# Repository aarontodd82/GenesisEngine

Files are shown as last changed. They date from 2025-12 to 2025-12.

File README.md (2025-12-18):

# Genesis Engine

**Authentic Sega Genesis / Mega Drive sound on real hardware.**

The Genesis Engine is a sound board and library that brings the iconic sound of the Sega Genesis to your projects. Featuring the **YM2612 FM synthesizer** and **SN76489 PSG** chips on a board easily controlled by Teensy/Arduino/ESP32

Play VGM music files, stream audio directly from an emulator, or use it as a standalone synthesizer. 

## The Board

Schematics, KiCad, & Gerbers are in the hardware folder, but if you just want to grab one:
[https://www.tindie.com/products/40905/](https://www.tindie.com/products/40905/)

- **Stereo output** — Full left/right channel separation
- **Accurate clocks** — Crystal oscillators tuned for correct pitch
- **FM and PSG in tune** — Both chips share a proper clock relationship
- **Upgraded Op-amp** — Designed for low noise

## Features

- **Real Chips** — YM2612 FM synthesis and SN76489 PSG, not emulation
- **VGM Playback** — Play music from Genesis, Mega Drive, Game Gear, and Master System
- **Multiple Playback Modes**
  - Flash memory (PROGMEM) for standalone operation
  - SD card for large music libraries
  - Serial streaming from PC
  - Real-time streaming from emulators (BlastEm)
- **Synthesis Utilities** — Direct chip control for custom sounds, MIDI synths, and sound effects
- **Cross-Platform** — Teensy 4.x, ESP32, Arduino Mega/Uno, and more
- **VGZ Support** — Native decompression on Teensy/ESP32
- **PCM/DAC Support** — Sampled drums and vocals on YM2612 channel 6
- **Smart Memory Management** — Automatically adapts to your board's capabilities

## Supported Systems for VGM

| System | FM Chip | PSG Chip | Support |
|---|---|---|---|
| Sega Genesis / Mega Drive | YM2612 | SN76489 | Full |
| Sega Master System | — | SN76489 | PSG only |
| Sega Game Gear | — | SN76489 | PSG only |
| ColecoVision | — | SN76489 | PSG only |
| IBM PCjr | — | SN76489 | PSG only |
| Tandy 1000 PCs | — | SN76489 | PSG only |

## Quick Start

### Wiring

Connect the Genesis Engine board to your microcontroller.

| Board Pin | Function | Arduino/Teensy | ESP32 | Configurable? |
|---|---|---|---|---|
| WR_P | PSG write strobe (active low) | 2 | 16 | Yes |
| WR_Y | YM2612 write strobe (active low) | 3 | 17 | Yes |
| IC_Y | YM2612 reset (active low) | 4 | 25 | Yes |
| A0_Y | YM2612 address/data select | 5 | 26 | Yes |
| A1_Y | YM2612 port select | 6 | 27 | Yes |
| SCK | Shift register clock | SPI | SPI | See below |
| SDI | Shift register data (MOSI) | SPI | SPI | See below |
| VCC | 5V power | — | — | — |
| GND | Ground | — | — | — |

**ESP32 Note:** GPIO 0-3 (boot/serial), 6-11 (flash), and 12/15 (boot strapping) must be avoided. The defaults above are safe for ESP32-WROOM-32 dev boards.

**SPI Pins** — By default, the library uses hardware SPI for fast data transfer. These pins are fixed per board:

| Board | SCK | SDI (MOSI) |
|---|-----|---|
| Teensy 4.x | 13 | 11 |
| ESP32 | 18 | 23 |
| Uno | 13 | 11 |
| Mega | 52 | 51 |

If you need different pins for SCK/SDI, set `USE_HARDWARE_SPI` to 0 in `GenesisBoard.cpp` to enable software SPI on any GPIO.

### Basic Usage

```cpp
#include <GenesisEngine.h>
#include "music.h"  // Your VGM converted to a header file

// Pin connections (directly configurable)
const uint8_t WR_P = 2, WR_Y = 3, IC_Y = 4, A0_Y = 5, A1_Y = 6;

// SCK/SDI ignored when using hardware SPI (default)
GenesisBoard board(WR_P, WR_Y, IC_Y, A0_Y, A1_Y, 0, 0);
GenesisEngine player(board);

void setup() {
    board.begin();
    player.play(music_data, music_length);
    player.setLooping(true);
}

void loop() {
    player.update();  // Call frequently for proper timing
}
```

### SD Card Playback

```cpp
#include <GenesisEngine.h>
#include <SD.h>

const uint8_t WR_P = 2, WR_Y = 3, IC_Y = 4, A0_Y = 5, A1_Y = 6;
GenesisBoard board(WR_P, WR_Y, IC_Y, A0_Y, A1_Y, 0, 0);
GenesisEngine player(board);

void setup() {
    SD.begin(BUILTIN_SDCARD);  // Teensy 4.1 built-in SD
    board.begin();
    player.playFile("/music/greenhill.vgm");
}

void loop() {
    player.update();
}
```

## Playback Modes

### Flash Memory (PROGMEM)
Store music directly in your microcontroller's flash. Convert VGM files with the included tool:

```bash
python examples/BasicPlayback/vgm2header.py song.vgm
```

### SD Card
Play VGM and VGZ files directly from SD. The SDCardPlayer example includes an interactive serial menu for browsing and playback control. Works best on Teensy or ESP32. Mega has limited support (see Platform Notes). Not supported on Arduino Uno due to RAM limits.

### Serial Streaming
Stream VGM files from your PC in real-time:

```bash
python examples/SerialStreaming/stream_vgm.py song.vgm
```

### Emulator Bridge
Stream audio directly from BlastEm or other Genesis emulators to hear games on real hardware as you play.

## Platform Notes

| Feature | Teensy 4.x | ESP32 | Mega | Uno |
|---|---|---|---|-----|
| PROGMEM playback | Yes | Yes | Yes | Yes |
| Serial streaming | Yes | Yes | Yes | Yes |
| SD card | Built-in | Yes | Limited* | No |
| VGZ decompression | Native | Native | Via tools | Via tools |
| PCM buffer size | 8KB+ | 4KB | 512 bytes | 256 bytes |

**Teensy 4.x is recommended**, especially for SD card playback. It offers fast GPIO, large memory, and built-in SD on the 4.1.

**Arduino Uno/Mega Limitation:** Due to AVR's 16-bit PROGMEM addressing, flash playback is limited to ~16KB (Uno) or ~60KB (Mega). Use `--strip-dac` when converting to fit more music. Uno does not support SD card (insufficient RAM). See the BasicPlayback example README for details.

*Mega SD support requires software SPI for the shift register due to pin conflicts. Results may vary—some VGM files with heavy DAC usage may have timing issues.

**ESP32 SD Note:** When using SD cards on ESP32, the shift register must use different pins (GPIO 4/13) than other examples (GPIO 18/23) because the SD card needs the hardware SPI bus. See the SDCardPlayer README for full wiring details.

## Examples

- **BasicPlayback** — VGM playback from flash memory
- **SDCardPlayer** — SD card player with serial menu
- **SerialStreaming** — Stream music from PC over USB
- **EmulatorBridge** — Real-time audio from Genesis emulators
- **SimpleSynth** — Direct chip control demo using synthesis utilities
- **MIDISynth** — Full MIDI synthesizer with voice allocation and patch management

## Tools

Each example includes relevant Python tools:

| Tool | Location | Description |
|---|---|---|
| `vgm2header.py` | examples/BasicPlayback/ | Convert VGM/VGZ to C header files |
| `vgm_prep.py` | examples/SDCardPlayer/ | Prepare VGM for SD (decompress, strip DAC) |
| `stream_vgm.py` | examples/SerialStreaming/ | Stream VGM from PC to board |

## Synthesis Utilities

For direct chip control without VGM playback, the library includes synthesis utilities in `synth/`:

```cpp
#include <GenesisBoard.h>
#include <synth/FMPatch.h>
#include <synth/FMFrequency.h>
#include <synth/PSGFrequency.h>
#include <synth/DefaultPatches.h>

GenesisBoard board(2, 3, 4, 5, 6, 13, 11);
FMPatch patch;

void setup() {
    board.begin();

    // Load a built-in FM patch
    memcpy_P(&patch, &defaultFMPatches[0], sizeof(FMPatch));
    FMPatchUtils::loadToChannel(board, 0, patch);
}

void playNote(uint8_t note) {
    FMFrequency::writeToChannel(board, 0, note);
    FMFrequency::keyOn(board, 0);
}

void stopNote() {
    FMFrequency::keyOff(board, 0);
}
```

### Available Modules

| Header | Description |
|---|---|
| `synth/FMFrequency.h` | MIDI note to YM2612 frequency conversion, key on/off |
| `synth/PSGFrequency.h` | MIDI note to PSG tone values, volume control |
| `synth/FMPatch.h` | FM patch structure and loading utilities |
| `synth/PSGEnvelope.h` | Software envelope generator for PSG |
| `synth/DefaultPatches.h` | 8 built-in FM patches and 4 PSG envelopes |

See the **SimpleSynth** example for a complete demo, or **MIDISynth** for a full synthesizer implementation.

## License

LGPL-2.1 — See [LICENSE](LICENSE) for details.

## Links

- [GitHub Repository](https://github.com/fm-90s/GenesisEngine)
- [FM-90s](https://fm-90s.com)

---

*Genesis Engine is not affiliated with or endorsed by Sega. Sega Genesis and Mega Drive are trademarks of Sega Corporation.*

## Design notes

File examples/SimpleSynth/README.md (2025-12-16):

# SimpleSynth

Direct chip control demo for the GenesisEngine board. Play notes on the YM2612 FM chip and SN76489 PSG using simple serial commands.

This example demonstrates the **synthesis utilities** in the GenesisEngine library, showing how to control the chips without VGM playback.

## Features

- Load FM patches from the built-in library
- Play notes by MIDI number
- PSG tone generation
- Simple serial command interface

## Quick Start

1. Upload the sketch to your board
2. Open Serial Monitor at 115200 baud
3. Try these commands:
   - `n60` — Play middle C on FM
   - `p3` — Switch to Lead Synth patch
   - `n72` — Play note 72 (C5)
   - `s` — Stop note
   - `t60` — Play middle C on PSG
   - `q` — Silence all
   - `?` — Show help

## Serial Commands

| Command | Description |
|---|---|
| `n<note>` | Play FM note (0-127, 60 = middle C) |
| `s` | Stop FM note |
| `p<num>` | Change FM patch (0-7) |
| `t<note>` | Play PSG tone on channel 0 |
| `q` | Silence all |
| `?` | Show help |

## Built-in Patches

| Slot | Sound |
|---|---|
| 0 | Bright EP (Electric Piano) |
| 1 | Synth Bass |
| 2 | Brass |
| 3 | Lead Synth |
| 4 | Organ |
| 5 | Strings |
| 6 | Pluck/Guitar |
| 7 | Bell/Chime |

## Using the Synthesis Utilities

This example shows the basics of direct chip control:

```cpp
#include <GenesisBoard.h>
#include <synth/FMPatch.h>
#include <synth/FMFrequency.h>
#include <synth/PSGFrequency.h>
#include <synth/DefaultPatches.h>

// Load a patch
FMPatch patch;
memcpy_P(&patch, &defaultFMPatches[0], sizeof(FMPatch));
FMPatchUtils::loadToChannel(board, 0, patch);

// Play a note
FMFrequency::writeToChannel(board, 0, 60);  // Set frequency
FMFrequency::keyOn(board, 0);               // Start note

// Stop the note
FMFrequency::keyOff(board, 0);

// PSG tone
PSGFrequency::playNote(board, 0, 60, 2);    // Channel 0, note 60, volume 2
```

## Building On This

For a full synthesizer with MIDI support, see the **MIDISynth** example.

## Pin Configuration

Adjust the pin definitions in the sketch to match your wiring to the Genesis Engine board.

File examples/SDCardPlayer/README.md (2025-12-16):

# SDCardPlayer

Play VGM files from an SD card with an interactive serial menu. This example turns the Genesis Engine into a standalone music player for Sega Genesis/Mega Drive soundtracks.

## Wiring

### Recommended: Teensy 4.1

Teensy 4.1 provides the best experience with built-in SD card slot, plenty of RAM, and full VGZ support.

### Arduino Uno - NOT SUPPORTED

Only 2KB RAM - not enough for SD library.

### Arduino Mega - Limited Support

Works but results may vary. Software SPI for the shift register is slower than Teensy's hardware SPI, which may affect timing on some VGM files. Use `vgm_prep.py` to prepare files.

The SD card and shift register both use SPI, but the CD74HCT164E shift register has no chip select pin. To avoid conflicts, **the shift register MUST use different pins** than the SD card.

| Genesis Engine Board | Arduino Pin |
|---|---|
| WR_P (PSG write) | 2 |
| WR_Y (YM2612 write) | 3 |
| IC_Y (YM2612 reset) | 4 |
| A0_Y (YM2612 addr)  | 5 |
| A1_Y (YM2612 port)  | 6 |
| **Shift CLK** | **7** ⚠️ |
| **Shift DATA** | **8** ⚠️ |

⚠️ **Do NOT connect shift register to pins 51/52!** Those are used by the SD card.

SD card uses Mega's hardware SPI:

| SD Card Module | Arduino Pin |
|---|---|
| CS | 53 |
| MOSI | 51 |
| MISO | 50 |
| SCK | 52 |
| VCC | 5V |
| GND | GND |

**Teensy 4.1:**

Uses the built-in SD card slot - no SD wiring needed. Genesis board can use the default hardware SPI pins since there's no conflict.

### ESP32 - Full Support

ESP32 works great with SD cards, but requires **different shift register pins** than other examples. The SD card needs the hardware SPI bus, and since the shift register has no chip select, they cannot share pins.

⚠️ **IMPORTANT:** The shift register pins are DIFFERENT from SerialStreaming and other examples!

| Genesis Engine Board | ESP32 GPIO |
|---|---|
| WR_P (PSG write) | 16 |
| WR_Y (YM2612 write) | 17 |
| IC_Y (YM2612 reset) | 25 |
| A0_Y (YM2612 addr)  | 26 |
| A1_Y (YM2612 port)  | 27 |
| **Shift CLK** | **4** ⚠️ |
| **Shift DATA** | **13** ⚠️  |

⚠️ **Do NOT use GPIO 18/23 for shift register!** Those are used by the SD card.

SD card uses ESP32's hardware SPI (VSPI):

| SD Card Module | ESP32 GPIO |
|---|---|
| CS | 5 |
| MOSI | 23 |
| MISO | 19 |
| SCK | 18 |
| VCC | 3.3V or 5V (check your module) |
| GND | GND |

**PlatformIO users:** Use the `esp32_sd` environment, not `esp32`.

---

## How to Use

1. **Prepare your files**: Place `.vgm` files in the root of a FAT32-formatted SD card. On Arduino Mega, use `vgm_prep.py` to convert `.vgz` files first:
   ```
   python vgm_prep.py song.vgz -o song.vgm
   ```

2. **Upload the sketch**: Open `SDCardPlayer.ino` in the Arduino IDE and upload it to your board.

3. **Open the Serial Monitor**: Go to **Tools > Serial Monitor** (or press `Ctrl+Shift+M`). Set the baud rate to **115200** using the dropdown in the bottom-right corner. You should see a welcome message and a `>` prompt.

4. **Control playback**: Type commands in the input field at the top and press Enter:
   | Command | Action |
   |---------|--------|
   | `list` | Show available VGM files |
   | `play 1` | Play file #1 (or use filename) |
   | `playlist name` | Play a playlist (name.txt) |
   | `stop` | Stop playback |
   | `pause` | Pause/resume |
   | `next` / `prev` | Skip tracks |
   | `loop` | Toggle looping |
   | `info` | Show current track status |
   | `help` | Full command list |

   Tip: You can also just type a number (e.g. `3`) to quickly play that file.

## Playlists

Create a `.txt` file on your SD card starting with `#PLAYLIST`:

```
#PLAYLIST
# My playlist - lines starting with # are comments
#
# Optional settings:
#   :shuffle  - randomize song order
#   :loop     - restart playlist when finished
#
# Songs: one per line, optionally with play count
#   song.vgm      - plays once
#   song.vgm,3    - plays 3 times (loops twice)
#
:shuffle
:loop

greenhill.vgm,2
starlight.vgm
boss.vgm,3
```

**Commands:**
- `playlist mylist` - loads and plays `mylist.txt`

**Auto-start:** Name your playlist `auto.txt` and it will play automatically when the board powers on - no serial connection needed.

## Tech Primer

The sketch creates a `GenesisBoard` (hardware driver) and `GenesisEngine` (player) instance. On startup, it initializes the SD card and scans the root directory for `.vgm`/`.vgz` files, storing up to 50 filenames (20 on AVR).

The main loop does two things: calls `player.update()` to process VGM commands in real-time, and polls the serial port for user input. Commands are parsed in `processCommand()` which maps text input to player API calls like `playFile()`, `pause()`, and `stop()`.

When you play a file, `GenesisEngine` opens it via `SDSource`, parses the VGM header for metadata (duration, loop points, chips used), then streams commands to the hardware. The player uses `micros()` to track elapsed time and processes chip writes at the correct 44100 Hz sample rate.

**Platform differences**: Teensy and ESP32 have enough RAM to decompress VGZ files on-the-fly and buffer PCM samples. AVR boards (Uno/Mega) lack this, so you must pre-process files with `vgm_prep.py`, which decompresses VGZ and inlines DAC samples directly into the command stream at a reduced sample rate.

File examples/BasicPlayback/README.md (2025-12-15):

# BasicPlayback Example

Play VGM/VGZ files from flash memory using the Genesis Engine library.

## Quick Start

A sample file `greenhill.vgz` is included. Convert it first:

1. **Convert your VGM file:**
   ```
   python vgm2header.py your_song.vgz
   ```
   The wizard will ask which platform you're using and handle the rest.

2. **Update the sketch:**
   ```cpp
   #include "your_song.h"
   ```
   And update the playChunked() calls:
   ```cpp
   player.playChunked(your_song_chunks, your_song_chunk_sizes,
                      YOUR_SONG_NUM_CHUNKS, YOUR_SONG_TOTAL_LEN);
   ```

3. **Upload and enjoy!**

## Batch Conversion

Skip the wizard with `-p` to specify platform directly:
```
python vgm2header.py *.vgz -p teensy41
```

## Platform Limits

Flash memory limits for VGM data vary by platform:

| Platform | Max VGM Size | Notes |
|---|---|---|
| **Teensy 4.1** | ~7 MB | Recommended for large files |
| **Teensy 4.0** | ~1.5 MB | |
| **ESP32** | ~2 MB | |
| **RP2040** | ~1.5 MB | |
| **Arduino Mega** | **60 KB** | 16-bit PROGMEM pointer limit |
| **Arduino Uno** | **16 KB** | Very limited flash |

### Arduino Limitations

**Arduino Uno and Mega have severe flash limitations** due to AVR's 16-bit PROGMEM addressing. The converter will automatically truncate files to fit.

For Arduino, use `--strip-dac` to remove PCM samples (drums):
```
python vgm2header.py song.vgz -p mega --strip-dac
```

This often reduces file size by 90%+ while keeping all FM and PSG music. A 500KB VGM typically becomes 30-50KB without DAC.

**For larger music libraries on Arduino, use the SDCardPlayer example instead.**

## Pin Configuration

Adjust the pin definitions in the sketch to match your wiring to the Genesis Engine board.

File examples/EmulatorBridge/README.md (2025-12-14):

# EmulatorBridge

This example turns your Genesis Engine board into a real-time audio output device for the BlastEm emulator. Play any Genesis/Mega Drive game and hear authentic sound through real YM2612 and SN76489 chips.

## Quick Start

1. **Upload the sketch** to your Genesis Engine board using the Arduino IDE or PlatformIO
2. **Download BlastEm** from [https://github.com/aarontodd82/blastem-genesis-engine/releases](https://github.com/aarontodd82/blastem-genesis-engine/releases) (Windows, macOS, and Linux binaries available)
3. **Connect the board** via USB
4. **Run BlastEm** with any ROM: `./blastem game.bin`

If the board is detected, you'll see: "Genesis Engine audio board found, using hardware audio"

That's it - all game audio now plays through the real chips.

## How It Works

When you play a game in BlastEm, the emulator intercepts every write to the YM2612 (FM synth) and SN76489 (PSG) registers. Instead of just emulating the sound, it streams those writes over USB serial to your Genesis Engine board at 1 Mbaud.

The board receives these commands in real-time and writes them to the actual chips. Audio stays in sync with the game since timing comes directly from the emulator.

### Board Compatibility

| Board | Buffer | FM + PSG | DAC/PCM |
|---|---|---|---|
| Arduino Uno | 512 bytes | Real hardware | Software (from PC) |
| Arduino Mega | 2 KB | Real hardware | Software (from PC) |
| Teensy 4.x | 32 KB | Real hardware | Real hardware |
| ESP32 | 16 KB | Real hardware | Real hardware |

**Arduino Uno/Mega**: FM synthesis and PSG play through real chips. DAC samples (used for voices, drums, sound effects in some games) play through BlastEm's software emulation on your PC. This hybrid approach works because DAC streaming requires more bandwidth than constrained boards can handle.

**Teensy 4.x/ESP32**: Full hardware audio - FM, PSG, and DAC all play through the real chips. BlastEm mutes its software audio completely.

## Troubleshooting

**No hardware detected**
- Check USB connection
- Verify the sketch is uploaded (LED should be on)
- Linux users: add yourself to the `dialout` group

**Audio glitches**
- Don't use fast-forward or turbo modes
- Avoid USB hubs - connect directly
- Close other programs using serial ports

**Notes hang when pausing**
- This is handled automatically - BlastEm silences the hardware when you pause or open menus

## Technical Details

### Protocol

The bridge uses VGM-style commands for chip writes:

| Command | Bytes | Description |
|---|---|---|
| `0x50 <val>` | 2 | Write to PSG |
| `0x52 <reg> <val>` | 3 | Write to YM2612 Port 0 |
| `0x53 <reg> <val>` | 3 | Write to YM2612 Port 1 |
| `0x61 <lo> <hi>` | 3 | Wait N samples (44.1kHz) |
| `0x62` | 1 | Wait 1/60 sec (NTSC frame) |
| `0x63` | 1 | Wait 1/50 sec (PAL frame) |
| `0x70-0x7F` | 1 | Wait 1-16 samples |
| `0x66` | 1 | End stream / reset |
| `0xAA` | 1 | Ping (connection handshake) |

### Connection Handshake

```
BlastEm                    Board
   |                         |
   |------- 0xAA PING ------>|
   |                         |
   |<-- 0x0F ACK + TYPE -----|
   |<------ 0x06 READY ------|
   |                         |
   |==== streaming begins ===|
```

The board type in the handshake response tells BlastEm which audio mode to use:
- Types 1-2 (Uno/Mega): Hybrid mode - stream FM/PSG to hardware, keep software DAC
- Types 4-5 (Teensy/ESP32): Full hardware mode - stream everything, mute software audio

### Data Flow

```
BlastEm (emulator)              USB Serial (1Mbaud)              Genesis Engine
┌──────────────────┐                                           ┌─────────────────┐
│  68000 CPU write │                                           │                 │
│  to $A04000      │ ──── 0x52 reg val ────────────────────────> Real YM2612    │
│  (YM2612)        │                                           │                 │
│                  │                                           │                 │
│  Z80 write to    │                                           │                 │
│  $7F11 (PSG)     │ ──── 0x50 val ────────────────────────────> Real SN76489   │
└──────────────────┘                                           └─────────────────┘
        │
        └── Wait commands encode timing at 44.1kHz sample resolution
```

### Timing Architecture

BlastEm runs with cycle-accurate emulation and tracks exactly when each register write occurs. It converts these timestamps into VGM-style wait commands:

1. **In BlastEm**: A `serial_bridge.c` module hooks into `ym2612.c` and `psg.c`
2. **Timing accumulation**: Cycles since last write are converted to 44.1kHz samples
3. **Wait encoding**: Uses efficient short waits (`0x70-0x7F`) when possible
4. **On the board**: `micros()` timing ensures writes happen at the correct intervals

The board's ring buffer absorbs USB timing jitter, keeping playback smooth even if USB batches data irregularly.

### Arduino Delay Buffer

On Arduino Uno/Mega, a frame-delay buffer (~67ms) synchronizes hardware FM/PSG with software DAC audio from BlastEm. This ensures both audio sources stay in sync despite different playback latencies.

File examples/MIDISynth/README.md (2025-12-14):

# MIDISynth

A MIDI synthesizer for the GenesisEngine board. Play the YM2612 FM chip and SN76489 PSG from any DAW, keyboard, or sequencer using real Sega Genesis hardware.

## Platform Requirements

**Teensy 4.x** works as a standalone USB MIDI instrument. Connect it to your computer and it appears as "Genesis Engine" in your MIDI device list. You can load custom patches using the included `genesis_patch.py` script, though the companion app below offers more features.

**Arduino Uno/Mega** requires the [GenesisEngineSynthApp](https://github.com/aarontodd82/GenesisEngineSynthApp) companion application. The app bridges your computer's MIDI to the Arduino over serial. Download releases for Windows, Mac, and Linux from the GitHub page. On Windows, you'll also need [LoopMIDI](https://www.tobias-erichsen.de/software/loopmidi.html) to create a virtual MIDI port for your DAW.

## Setup

### Teensy

1. In Arduino IDE: **Tools → USB Type → Serial + MIDI**
2. Upload the sketch
3. Connect via USB - your computer sees "Genesis Engine"

### Arduino

1. Upload the sketch
2. Run GenesisEngineSynthApp
3. Select your Arduino's COM port and connect
4. On Windows: Create a LoopMIDI port, select it in the app, then route your DAW to that port

## Loading Patches

The synth starts with 8 built-in FM patches. To load custom patches:

**Using GenesisEngineSynthApp** (recommended): The app provides a patch browser, bank management, and real-time parameter editing.

**Using genesis_patch.py** (Teensy only):
```bash
pip install python-rtmidi
python genesis_patch.py load piano.tfi 1      # Load to channel 1
python genesis_patch.py bank sonic2.gyb       # Load a GYB bank
```

Supported formats: TFI, DMP, GYB. Find patches at [VGMRips](https://vgmrips.net) or create your own with [Furnace Tracker](https://github.com/tildearrow/furnace).

## Quick Reference

### MIDI Channels

| Channel | Hardware |
|---|---|
| 1-6 | YM2612 FM |
| 7-9 | SN76489 Tone |
| 10 | SN76489 Noise |

### Synth Modes

- **Multi-timbral** (default): Each FM channel plays independently
- **Poly**: Channel 1 controls all 6 FM voices polyphonically

Switch with CC 126 (multi) or CC 127 (poly).

### Key MIDI Controls

| Message | Effect |
|---|---|
| Program Change | Select patch slot |
| Pitch Bend | ±2 semitones (FM) |
| CC 1 | Vibrato depth (FM) |
| CC 7 | Volume |
| CC 10 | Pan (FM) |
| CC 64 | Sustain pedal (FM) |

### Real-Time Parameter CCs

| CC | Parameter |
|----|---|
| 14 | Algorithm (0-7) |
| 15 | Feedback (0-7) |
| 16-19 | Operator 1-4 Total Level |

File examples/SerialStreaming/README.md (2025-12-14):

# SerialStreaming

Stream VGM files from your PC directly to the Genesis Engine board over USB. No SD card needed - just plug in, run the script, and listen to Sega Genesis music on real hardware.

## Requirements

- Arduino Uno, Mega, Teensy 4.x, or ESP32
- Python 3 with pyserial (`pip install pyserial`)
- USB cable

## Quick Start

1. Upload `SerialStreaming.ino` to your board
2. Run the streamer:

```bash
python stream_vgm.py
```

This launches an interactive wizard that finds VGM files and your board automatically.

## Command Line Usage

```bash
# Basic playback
python stream_vgm.py song.vgm

# Specify port manually
python stream_vgm.py song.vgm --port COM3
python stream_vgm.py song.vgm --port /dev/ttyUSB0

# Loop forever (Ctrl+C to stop)
python stream_vgm.py song.vgm --loop

# Loop 3 times
python stream_vgm.py song.vgm --loop 3

# List available serial ports
python stream_vgm.py --list-ports
```

## DAC/PCM Options

Some VGM files contain sampled audio (drums, voices). These require high throughput and may not play smoothly on slower boards.

```bash
# Reduce DAC sample rate (1=full, 2=half, 4=quarter)
python stream_vgm.py song.vgm --dac-rate 2

# Strip DAC entirely (FM/PSG only, smallest bandwidth)
python stream_vgm.py song.vgm --no-dac
```

By default, Uno/Mega use 1/4 DAC rate automatically. Teensy uses full rate.

## Troubleshooting

**No response from device**
- Make sure the sketch is uploaded
- Check that the baud rate matches (default: 1000000)
- Try unplugging and replugging the USB cable

**Audio glitches or stuttering**
- Try `--dac-rate 2` or `--dac-rate 4`
- Use `--no-dac` for problematic files
- Ensure no other programs are using the serial port

**Wrong port detected**
- Use `--list-ports` to see available ports
- Specify manually with `--port`

---

## How It Works

The system streams VGM commands from your PC to the board in real-time using a custom binary protocol.

### Architecture

```
PC (stream_vgm.py)                    Board (SerialStreaming.ino)
┌──────────────────┐                  ┌──────────────────────────┐
│ Load VGM/VGZ     │                  │                          │
│       ↓          │                  │   Ring Buffer            │
│ Preprocess:      │   1Mbaud USB     │   ┌────────────────┐     │
│ - Inline PCM     │ ═══════════════> │   │ ░░░░░░░▓▓▓▓▓▓ │     │
│ - Optimize waits │   Chunked data   │   └───────┬────────┘     │
│ - Reduce DAC rate│                  │           ↓              │
│       ↓          │                  │   Command Parser         │
│ Chunk + checksum │                  │           ↓              │
│       ↓          │                  │   ┌───────┴───────┐      │
│ Send via serial  │                  │   ↓               ↓      │
└──────────────────┘                  │ YM2612 (FM)   SN76489    │
                                      └──────────────────────────┘
```

### Protocol

Data is sent in checksummed chunks to handle serial errors:

```
[0x01][length][data...][XOR checksum]
```

The board responds with:
- `0x06` (ACK) - chunk received OK, ready for more
- `0x15` (NAK) - bad checksum, please resend

### Timing

VGM files run at 44100 Hz. The board uses `micros()` to schedule commands precisely. Wait commands tell the board how many samples to delay before the next chip write.

### Buffering

The board fills its ring buffer before starting playback:
- Uno: 512 bytes (384 before play)
- Mega: 2KB (1.5KB before play)
- Teensy: 4KB (3KB before play)

This absorbs USB latency jitter and keeps playback smooth.

### DAC Handling

VGM files store PCM samples in a separate data block. The Python script inlines these samples directly into the command stream, so the board doesn't need RAM for sample storage. For slow boards, it skips samples to reduce bandwidth.

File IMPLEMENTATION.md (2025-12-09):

# FM-90s Genesis Engine - Implementation Guide

## Project Overview

**Name:** FM-90s Genesis Engine
**Purpose:** A simple, multi-platform Arduino library for playing VGM files on the FM-90s Genesis Engine sound board (YM2612 FM + SN76489 PSG)
**Target Audience:** Hobbyists and makers who want easy VGM playback with minimal configuration

### Supported Systems (VGM Playback)

| System | FM Chip | PSG Chip | Support Level |
|---|---|---|---|
| Sega Genesis / Mega Drive | YM2612 | SN76489 | Full |
| Sega Game Gear | - | SN76489 | Full (PSG only) |
| Sega Master System | - | SN76489 | Full (PSG only) |

---

## Goals

1. **Maximum Compatibility** - Works on Arduino Uno through Teensy 4.1
2. **Zero Configuration** - Auto-detects platform and enables appropriate features
3. **Simple API** - Users can play music with minimal code
4. **Self-Contained** - Single library include, no complex dependencies
5. **Progressive Features** - Basic features everywhere, advanced features on capable hardware

---

## Platform Support Matrix

| Feature | Arduino AVR | ESP32 | Teensy 4.x |
|---|---|---|---|
| PROGMEM playback | Yes | Yes | Yes |
| Serial streaming | Yes (VGM only) | Yes | Yes |
| SD card playback | With SD module | Yes | Yes (built-in on 4.1) |
| VGZ decompression | No (use tool) | Yes | Yes |
| USB MIDI instrument | No | No | Yes |
| DAC pre-render | No | No | Yes (with Audio Board) |
| Large buffers | No (256B) | Yes (4KB) | Yes (8KB+) |

---

## Architecture Decisions

### Platform Detection
- Automatic via compiler macros (`TEENSYDUINO`, `ARDUINO_ARCH_AVR`, etc.)
- No user configuration required
- Optional override defines if needed

### Pin Configuration
- Runtime configurable via constructor
- User passes their pin numbers, library handles the rest
- No compile-time pin definitions to confuse users

### VGM/VGZ Handling
- **Arduino AVR:** Python tool converts VGZ → VGM → C header (PROGMEM)
- **Arduino AVR Serial:** Requires pre-decompressed VGM files
- **Teensy/ESP32:** Native VGZ decompression using uzlib

### Timing Strategy
- Cooperative `update()` model with `micros()` for basic playback
- Timer interrupts on Teensy for sample-accurate timing
- Smart timing pattern from reference implementation (tracks elapsed time, only waits if needed)

### SD Card
- Conditional compilation - only included if platform supports it
- Uses standard Arduino SD library for compatibility
- Teensy uses `BUILTIN_SDCARD` for 4.1

### Serial Menu
- Optional include (`GenesisEngineMenu.h`)
- Commands: list files, play, stop, pause, next, previous, loop toggle
- Works over any Stream (Serial, Serial1, etc.)

### MIDI Instrument Mode
- Teensy-only (USB MIDI)
- Phase 2 feature
- Maps MIDI notes to YM2612 FM channels
- **Deflemask Patch Support:** Load .dmp (Deflemask Preset) files to use custom FM instruments
  - Deflemask is a popular chiptune tracker that exports YM2612 patches
  - Goal: Load patches from SD card and use them as MIDI instruments
  - Each MIDI channel can have a different Deflemask patch assigned

### DAC Pre-render (Phase 2)
- Teensy with Audio Board only
- Pre-renders PCM to temp file for smooth playback
- Based on reference implementation's proven approach

---

## Formats Supported

### VGM (Video Game Music)
- Standard format, widely available
- Large file sizes, especially with DAC
- Best for Teensy/ESP32 with plenty of flash

### GEP (Genesis Engine Packed) - NEW!
- Custom optimized format for AVR
- 2-4x smaller than VGM (sometimes 10-20x for DAC-heavy files)
- Multi-chunk support for songs larger than 32KB
- Same playback quality as VGM
- See `docs/GEP_FORMAT.md` for specification

#### GEP Compression Results

| Song | VGM Size | GEP (no DAC) | GEP (with DAC) |
|---|---|---|---|
| Green Hill Zone | 509 KB | 21 KB (4%) | 271 KB (53%) |
| Stage 7 Prarie | 305 KB | 71 KB (23%) | N/A |

---

## Library Structure

```
GenesisEngine/
├── library.properties              # Arduino library metadata
├── keywords.txt                    # Syntax highlighting
├── README.md                       # User documentation
├── IMPLEMENTATION.md               # This file
│
├── docs/
│   └── GEP_FORMAT.md               # GEP format specification
│
├── src/
│   ├── GenesisEngine.h             # Main VGM player
│   ├── GenesisEngine.cpp           # VGM player implementation
│   │
│   ├── GEPPlayer.h                 # GEP format player
│   ├── GEPPlayer.cpp               # GEP player implementation
│   │
│   ├── GenesisBoard.h              # Hardware abstraction
│   ├── GenesisBoard.cpp            # YM2612 + SN76489 driver
│   │
│   ├── VGMParser.h                 # VGM format parsing
│   ├── VGMParser.cpp               # Command processing
│   │
│   ├── VGMCommands.h               # VGM command definitions
│   │
│   ├── sources/
│   │   ├── VGMSource.h             # Abstract base class
│   │   ├── ProgmemSource.h         # Read from PROGMEM
│   │   ├── ProgmemSource.cpp
│   │   ├── SDSource.h              # SD card file source (conditional)
│   │   └── SDSource.cpp
│   │
│   ├── menu/
│   │   ├── SDPlayerMenu.h          # Serial menu for SD player
│   │   ├── SDPlayerMenu.cpp
│   │   ├── Playlist.h              # M3U playlist parser
│   │   └── Playlist.cpp
│   │
│   ├── config/
│   │   ├── platform_detect.h       # Auto-detection macros
│   │   └── feature_config.h        # Feature enable/disable logic
│   │
│   └── teensy/                     # Teensy-specific (conditional)
│       ├── VGZDecompressor.h       # uzlib wrapper
│       ├── VGZDecompressor.cpp
│       ├── DACPrerender.h          # DAC pre-rendering (Phase 2)
│       ├── DACPrerender.cpp
│       ├── MidiInstrument.h        # MIDI mode (Phase 2)
│       └── MidiInstrument.cpp
│
├── examples/
│   ├── BasicPlayback/
│   │   └── BasicPlayback.ino       # Simplest example - PROGMEM
│   ├── GEPPlayback/
│   │   └── GEPPlayback.ino         # GEP format playback
│   ├── SDCardPlayer/
│   │   └── SDCardPlayer.ino        # SD card + serial menu (combined)
│   ├── SerialStreaming/
│   │   ├── SerialStreaming.ino     # Stream VGM over serial from PC
│   │   └── StreamingProtocol.h     # Binary protocol definitions
│   └── MidiInstrument/
│       └── MidiInstrument.ino      # Teensy USB MIDI (Phase 4)
│
└── tools/
    ├── stream_vgm.py               # Stream VGM from PC (companion to SerialStreaming)
    ├── vgm_prep.py                 # Prepare VGM for SD card (decompress, strip DAC)
    ├── vgm2header.py               # Convert VGM/VGZ to C header (VGM format)
    ├── vgm2gep.py                  # Convert VGM/VGZ to GEP format
    ├── vgm_analyze.py              # Analyze VGM file structure
    └── README.md                   # Tool documentation
```

---

## Reference Implementation Locations

The following files from the MIDI-Player project contain code and patterns to reference:

**Project Root:** `C:\Users\aaron\OneDrive\Documents\PlatformIO\Projects\MIDI-Player`

### Hardware Interface (Genesis Board)

| File | Purpose | Key Code |
|---|---|---|
| `src/genesis_board.h` | YM2612 + SN76489 class definition | Pin config, timing constants, method signatures |
| `src/genesis_board.cpp` | Hardware driver implementation | SPI bit-bang, write timing, DAC streaming mode |

**Key Patterns:**
- Smart unified timing with `lastWriteTime_` tracking
- `waitIfNeeded(uint32_t minMicros)` - only delays if necessary
- Bit reversal for SN76489
- DAC streaming mode optimization (latch address once)

**Timing Constants:**
```cpp
YM_BUSY_US = 5      // YM2612 busy flag duration
PSG_BUSY_US = 9     // SN76489 write delay
```

### VGM Parsing & Playback

| File | Purpose | Key Code |
|---|---|---|
| `src/vgm_file.h` | VGM format definitions, ChipType enum | Header structure, command bytes |
| `src/vgm_file.cpp` | Streaming parser with gzip support | Loop handling, PCM data blocks, seeking |
| `src/vgm_player.h` | Player state machine | Timing model, command dispatch |
| `src/vgm_player.cpp` | VGM command processing | All chip routing, DAC handling |

**Key Patterns:**
- Sample-accurate timing at 44.1kHz (`MICROS_PER_SAMPLE = 22.675737`)
- Double-precision accumulator for fractional timing (`nextSampleTimeF_`)
- Loop snapshot capture for seamless looping
- PCM data bank management

**VGM Commands Handled:**
- `0x50`: SN76489 PSG write
- `0x52`/`0x53`: YM2612 port 0/1 writes
- `0x61`: Wait N samples
- `0x62`: Wait 735 samples (1/60 sec)
- `0x63`: Wait 882 samples (1/50 sec)
- `0x66`: End of data
- `0x67`: Data block (PCM samples)
- `0x70-0x7F`: Short delays (1-16 samples)
- `0x80-0x8F`: YM2612 DAC + delay combined
- `0xE0`: PCM data bank seek

### DAC Pre-rendering (Phase 2)

| File | Purpose | Key Code |
|---|---|---|
| `src/dac_prerender.h` | Pre-renderer class definition | Buffer management |
| `src/dac_prerender.cpp` | PCM extraction and file writing | Scan VGM, extract DAC, write temp file |
| `src/audio_stream_dac_prerender.h` | AudioStream for playback | Ring buffer, sync with VGM timing |
| `src/audio_stream_dac_prerender.cpp` | Stream implementation | `refillBuffer()`, mixing |

**Key Pattern:** Pre-renders all DAC commands to linear 44.1kHz stream, outputs to `/TEMP/~dac.tmp`

### Compression (VGZ)

| File | Purpose | Key Code |
|---|---|---|
| `src/vgm_file.cpp` | gzip detection and decompression | Uses uzlib library |

**Pattern:** Check first two bytes for gzip magic (`0x1F 0x8B`), decompress on-the-fly

### Player Architecture

| File | Purpose | Key Code |
|---|---|---|
| `src/player_manager.h/cpp` | Lifecycle management | Callback-driven async, single player instance |
| `src/player_config.h` | Dependency injection | All subsystem pointers in one struct |
| `src/playback_state.h/cpp` | Status tracking | STOPPED/PLAYING/PAUSED states |

**Key Patterns:**
- Callback-driven async operations
- Single player instance at a time (saves RAM)
- Clean state machine

### Audio System (Teensy)

| File | Purpose | Key Code |
|---|---|---|
| `src/audio_system.h/cpp` | SGTL5000 setup | Mixer gains, effects |
| `src/audio_globals.h` | Extern declarations | Global audio objects |

---

## Serial Menu Commands

```
FM-90s Genesis Engine
=====================
Commands:
  list          - List VGM files on SD card
  play <n>      - Play file number N
  play <name>   - Play file by name
  stop          - Stop playback
  pause         - Pause/resume
  next          - Next track
  prev          - Previous track
  loop          - Toggle loop mode
  info          - Show current track info
  help          - Show this menu
```

---

## API Design

### Minimal Example (PROGMEM)

```cpp
#include <GenesisEngine.h>
#include "music/greenhill.h"

GenesisBoard board(WR_SN, WR_YM, IC_YM, A0_YM, A1_YM, SCK_PIN, SDI_PIN);
GenesisEngine player(board);

void setup() {
  board.begin();
  player.play(greenhill_vgm, sizeof(greenhill_vgm));
}

void loop() {
  player.update();
}
```

### SD Card Example

```cpp
#include <GenesisEngine.h>
#include <SD.h>

GenesisBoard board(WR_SN, WR_YM, IC_YM, A0_YM, A1_YM, SCK_PIN, SDI_PIN);
GenesisEngine player(board);

void setup() {
  SD.begin(BUILTIN_SDCARD);
  board.begin();
  player.playFile("/vgm/sonic.vgm");
}

void loop() {
  player.update();
}
```

### With Menu

```cpp
#include <GenesisEngine.h>
#include <GenesisEngineMenu.h>
#include <SD.h>

GenesisBoard board(WR_SN, WR_YM, IC_YM, A0_YM, A1_YM, SCK_PIN, SDI_PIN);
GenesisEngine player(board);
GenesisEngineMenu menu(player, Serial);

void setup() {
  Serial.begin(115200);
  SD.begin(BUILTIN_SDCARD);
  board.begin();
  menu.begin();
}

void loop() {
  player.update();
  menu.update();
}
```

### Full API

```cpp
class GenesisEngine {
public:
  GenesisEngine(GenesisBoard& board);

  // Playback control
  bool play(const uint8_t* data, size_t length);  // PROGMEM
  bool playFile(const char* path);                 // SD card
  bool playStream(Stream& stream);                 // Serial/other
  void stop();
  void pause();
  void resume();

  // Must call frequently
  void update();

  // Status
  bool isPlaying() const;
  bool isPaused() const;
  bool isFinished() const;

  // Settings
  void setLooping(bool loop);
  bool isLooping() const;

  // Info (if available)
  uint32_t getCurrentSample() const;
  uint32_t getTotalSamples() const;
  const char* getTrackName() const;  // From GD3 tag
};
```

---

## Development Phases

### Phase 1: Core Library & Tools
- [ ] GenesisBoard hardware driver
- [ ] VGM parser (no compression)
- [ ] PROGMEM source
- [ ] Basic timing with `update()`
- [ ] Platform detection
- [ ] vgm2header.py converter (needed for testing)
- [ ] Basic example

### Phase 2: SD Card Support + Serial Menu (SDCardPlayer)
- [ ] SDSource - VGMSource implementation for SD card files
- [ ] Serial menu interface (combined with SD player, not separate)
- [ ] M3U playlist support with loop counts
- [ ] Python tools for VGM preparation:
  - [ ] vgm_prep.py - Decompress VGZ, strip/reduce DAC, validate for target platform
- [ ] Helpful error messages pointing users to preparation tools
- [ ] Platform-specific limitations documented and enforced

**See "SD Card Player Design" section below for full details.**

### Phase 3: Teensy Enhancements
- [ ] VGZ decompression (uzlib)
- [ ] Larger buffers
- [ ] Timer-based accurate timing
- [ ] Loop handling from reference impl

### Phase 4: Advanced Features
- [ ] MIDI instrument mode
  - [ ] Basic MIDI note on/off to YM2612 channels
  - [ ] Deflemask .dmp patch file loading
  - [ ] Patch assignment per MIDI channel
  - [ ] Velocity sensitivity
- [ ] GD3 tag parsing
- [ ] Fade out on loop

### Phase 5: Documentation & Polish
- [ ] Web-based converter
- [ ] Comprehensive documentation
- [ ] More examples

### Phase 6: DAC Pre-render (Teensy + Audio Board)
- [ ] DAC pre-rendering system
- [ ] AudioStream integration
- [ ] Temp file management

---

## SD Card Player Design

### Overview

The SDCardPlayer example combines SD card playback with an interactive serial menu. Users can browse files, play songs, manage playlists, and control playback via serial terminal.

### SPI Bus Sharing (Critical Issue)

**Problem:** Both the Genesis Engine shift register and SD card use SPI:
- Shift register: Uses hardware SPI (MOSI/SCK) for fast data output
- SD card: Also uses hardware SPI (MOSI/MISO/SCK + CS)

**Solution:** SPI bus sharing is supported - both devices can coexist on the same SPI bus with different chip select (CS) pins:
- Shift register: No CS pin (directly connected, always receives data)
- SD card: Uses dedicated CS pin (directly directly typically pin 10 on Uno, pin 53 on Mega, BUILTIN_SDCARD on Teensy 4.1)

**Implementation:**
1. SD card operations use `SPI.beginTransaction()` / `SPI.endTransaction()`
2. GenesisBoard already uses `SPI.beginTransaction()` with SPISettings
3. Both can share the bus - SD library handles CS automatically
4. **Caution:** During SD reads, shift register may receive garbage data (but WR pins are high, so it's ignored)

**Workaround if issues arise:** Fall back to software bit-bang for shift register (set `USE_HARDWARE_SPI 0` in GenesisBoard.cpp) - uses different pins than SD card.

### Platform Support Matrix - SD Card

| Platform | SD Support | VGZ Support | DAC Support | Notes |
|---|---|---|---|---|
| Arduino Uno | Yes* | No | Limited | 2KB RAM, FM+PSG only recommended |
| Arduino Mega | Yes* | No | Limited | 8KB RAM, small DAC files may work |
| Teensy 4.1 | Yes (built-in) | Yes | Full | 1MB RAM, no limitations |
| Teensy 4.0 | Yes (external) | Yes | Full | 1MB RAM |
| ESP32 | Yes | Yes | Full | 520KB RAM |

*Requires external SD module (SPI-based)

### Arduino Uno/Mega Limitations

**RAM Constraints:**
- Uno: 2KB total, ~1KB available after stack/globals
- Mega: 8KB total, ~6KB available

**What works:**
- VGM files (uncompressed) - read byte-by-byte from SD
- FM synthesis (YM2612) - no buffering needed
- PSG audio (SN76489) - no buffering needed

**What doesn't work well:**
- VGZ files - decompression needs ~32KB buffer
- Heavy DAC/PCM - needs sample buffering, causes timing issues
- Very large files - no issue with streaming, but limited error recovery

**Recommendations for Uno/Mega users:**
1. Use `.vgm` files only (not `.vgz`)
2. Strip DAC data for consistent playback: `python tools/vgm_prep.py song.vgz --strip-dac`
3. Or reduce DAC rate: `python tools/vgm_prep.py song.vgz --dac-rate 4`
4. Keep playlist files small

### SD Card Hardware Setup

**Arduino Uno:**
```
SD Module    Arduino Uno
---------    -----------
CS      -->  Pin 10 (configurable)
MOSI    -->  Pin 11 (hardware SPI)
MISO    -->  Pin 12 (hardware SPI)
SCK     -->  Pin 13 (hardware SPI)
VCC     -->  5V
GND     -->  GND
```

**Arduino Mega:**
```
SD Module    Arduino Mega
---------    ------------
CS      -->  Pin 53 (configurable)
MOSI    -->  Pin 51 (hardware SPI)
MISO    -->  Pin 50 (hardware SPI)
SCK     -->  Pin 52 (hardware SPI)
VCC     -->  5V
GND     -->  GND
```

**Teensy 4.1:**
- Built-in SD card slot, use `BUILTIN_SDCARD` for CS

**ESP32:**
- Default SPI pins vary by board, typically:
  - CS: GPIO 5
  - MOSI: GPIO 23
  - MISO: GPIO 19
  - SCK: GPIO 18

### Serial Menu Commands

```
Genesis Engine SD Player
========================
Commands:
  list              List VGM/VGZ files on SD card
  play <n>          Play file by number
  play <filename>   Play file by name
  stop              Stop playback
  pause             Pause/resume playback
  next              Next track (playlist mode)
  prev              Previous track (playlist mode)
  loop              Toggle loop mode
  playlist          Start playlist (plays playlist.m3u)
  playlist <file>   Start specific playlist
  info              Show current track info
  help              Show this menu
```

### Playlist Format (M3U)

Simple M3U format with optional extended info for loop counts:

```m3u
#EXTM3U
#EXTINF:180,Song Title - loop:3
song1.vgm
#EXTINF:120,Another Song - loop:0
song2.vgm
plain_song.vgm
```

- `loop:N` in EXTINF comment sets loop count (0 = infinite, omit = play once)
- Plain filenames (no EXTINF) play once
- Lines starting with `#` (except EXTINF) are ignored
- Relative paths from SD root

### Error Messages and User Guidance

The serial menu should provide helpful error messages:

```
ERROR: Cannot open 'song.vgz'
  VGZ files are not supported on Arduino Uno/Mega.
  Please decompress first:
    python tools/vgm_prep.py song.vgz -o song.vgm

ERROR: DAC playback issues detected
  This file has heavy DAC/PCM usage which may not play well on Uno/Mega.
  Try stripping DAC data:
    python tools/vgm_prep.py song.vgm --strip-dac -o song_nodac.vgm
  Or reducing sample rate:
    python tools/vgm_prep.py song.vgm --dac-rate 4 -o song_lowdac.vgm

ERROR: SD card not found
  Please check:
  1. SD card is inserted
  2. SD card is FAT16/FAT32 formatted
  3. CS pin is correctly configured (currently: pin 10)
```

### Python Preparation Tool (vgm_prep.py)

New unified tool for preparing VGM files for SD card playback:

```bash
# Basic usage - decompress VGZ to VGM
python tools/vgm_prep.py song.vgz -o song.vgm

# Strip all DAC data (FM+PSG only)
python tools/vgm_prep.py song.vgm --strip-dac -o song_nodac.vgm

# Reduce DAC sample rate (1/4 rate)
python tools/vgm_prep.py song.vgm --dac-rate 4 -o song_lowdac.vgm

# Validate for specific platform
python tools/vgm_prep.py song.vgm --validate uno
python tools/vgm_prep.py song.vgm --validate mega
python tools/vgm_prep.py song.vgm --validate teensy

# Batch process a directory
python tools/vgm_prep.py ./vgm_folder/ --strip-dac --output-dir ./sd_card/
```

### File Organization on SD Card

Recommended structure:
```
SD Card Root/
├── playlist.m3u        # Default playlist
├── sonic.vgm
├── streets.vgm
├── thunder.vgm
└── playlists/
    ├── genesis.m3u
    └── gamegear.m3u
```

### Implementation Notes

**SDSource class:**
- Wraps Arduino SD File object
- Implements VGMSource interface (read, seek, etc.)
- Handles file open/close
- Reports file size for progress display

**Menu class:**
- Reads commands from Serial
- Parses and dispatches to player
- Displays status and errors
- Non-blocking design (checks Serial.available() in loop)

**Playlist class:**
- Parses M3U files
- Tracks current position
- Handles loop counts per track
- Signals when playlist is complete

---

## Technical Notes

### Pin Naming Convention

The FM-90s Genesis Engine board uses the following pin labels:

| Pin | Description |
|-----|---|
| WR_P | SN76489 (PSG) write strobe (active low) |
| WR_Y | YM2612 write strobe (active low) |
| IC_Y | YM2612 reset (active low) |
| A0_Y | YM2612 address bit 0 |
| A1_Y | YM2612 address bit 1 (port select) |
| SCK  | Shift register clock (CD74HCT164E) |
| SDI  | Shift register data in |

### YM2612 Write Sequence
1. Set A1_Y (port select: 0 or 1)
2. Set A0_Y = LOW (address mode)
3. Shift out 8-bit register address via SCK/SDI
4. Pulse WR_Y LOW (minimum 1μs)
5. Set A0_Y = HIGH (data mode)
6. Shift out 8-bit data value
7. Pulse WR_Y LOW (triggers BUSY flag, wait 5μs before next write)

### SN76489 Write Sequence
1. Bit-reverse the data byte (hardware wiring quirk)
2. Shift out 8 bits via SCK/SDI
3. Pulse WR_P LOW (minimum 8μs pulse width)
4. Wait 9μs before next write

### VGM Timing
- VGM runs at 44100 Hz sample rate
- 1 sample = 22.675737 microseconds
- Commands specify delays in samples
- Accumulate fractional time to prevent drift

---

## Development vs Distribution

### For Development (Us)

Use PlatformIO with the included `platformio.ini`:

1. Open `GenesisEngine` folder in VS Code with PlatformIO
2. Select target board (mega, teensy41, etc.) from PlatformIO toolbar
3. Edit code in `src/`, test sketches in `examples/`
4. Build and upload directly - no copying files

The `platformio.ini` treats the library source as a local dependency, so changes are immediate.

### For Distribution (End Users)

The same folder works as an Arduino library:

1. User downloads/clones the `GenesisEngine` folder
2. Copies it to their Arduino `libraries/` folder (or installs via ZIP)
3. Opens examples from File → Examples → GenesisEngine
4. The `platformio.ini` file is ignored by Arduino IDE

**Important:** When distributing, do NOT include:
- `tools/test_vgm/*.h` (generated test files - too large)
- `.pio/` folder (PlatformIO build cache)

Keep in the distribution:
- `tools/vgm2header.py` (users need this)
- `tools/vgm_analyze.py` (optional but helpful)
- `tools/test_vgm/README.md` (instructions)

---

## Notes & Reminders

- The FM-90s Genesis Engine board uses a CD74HCT164E shift register for data
- Pins are directly connected (directly directly directly...)
- Reference implementation is battle-tested on Teensy 4.1
- Keep Arduino Uno RAM usage under 1.5KB to leave room for user code
- Test on real hardware frequently during development

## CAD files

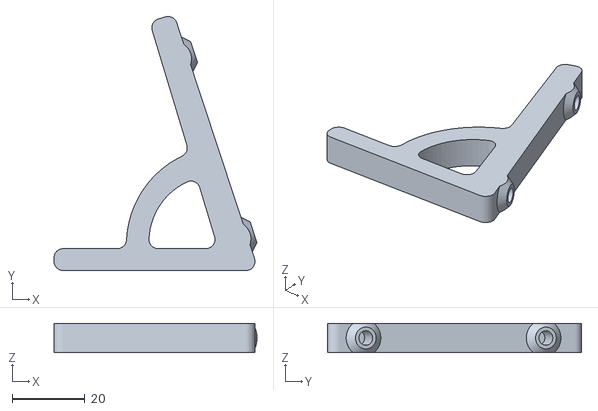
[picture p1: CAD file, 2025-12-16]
hardware/Stand.stl
55.6 x 69.6 x 8.00

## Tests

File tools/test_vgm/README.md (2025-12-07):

# Test VGM Files

Place your VGM and VGZ files here for testing.

## Converting to C Headers

From this directory, run:

```bash
python ../vgm2header.py yourfile.vgm
```

Or convert all files at once:

```bash
python ../vgm2header.py *.vgm *.vgz
```

The generated `.h` files can be copied to your Arduino sketch folder.

## Where to Find VGM Files

- **Project2612**: https://project2612.org/ (Genesis/Mega Drive)
- **SMS Power**: https://www.smspower.org/Music/VGMs (Master System, Game Gear)
- **VGMRips**: https://vgmrips.net/ (Various systems)

## Supported Formats

| Extension | Description |
|---|---|
| .vgm | Uncompressed VGM |
| .vgz | Gzip-compressed VGM |

Both formats are supported by the converter tool.

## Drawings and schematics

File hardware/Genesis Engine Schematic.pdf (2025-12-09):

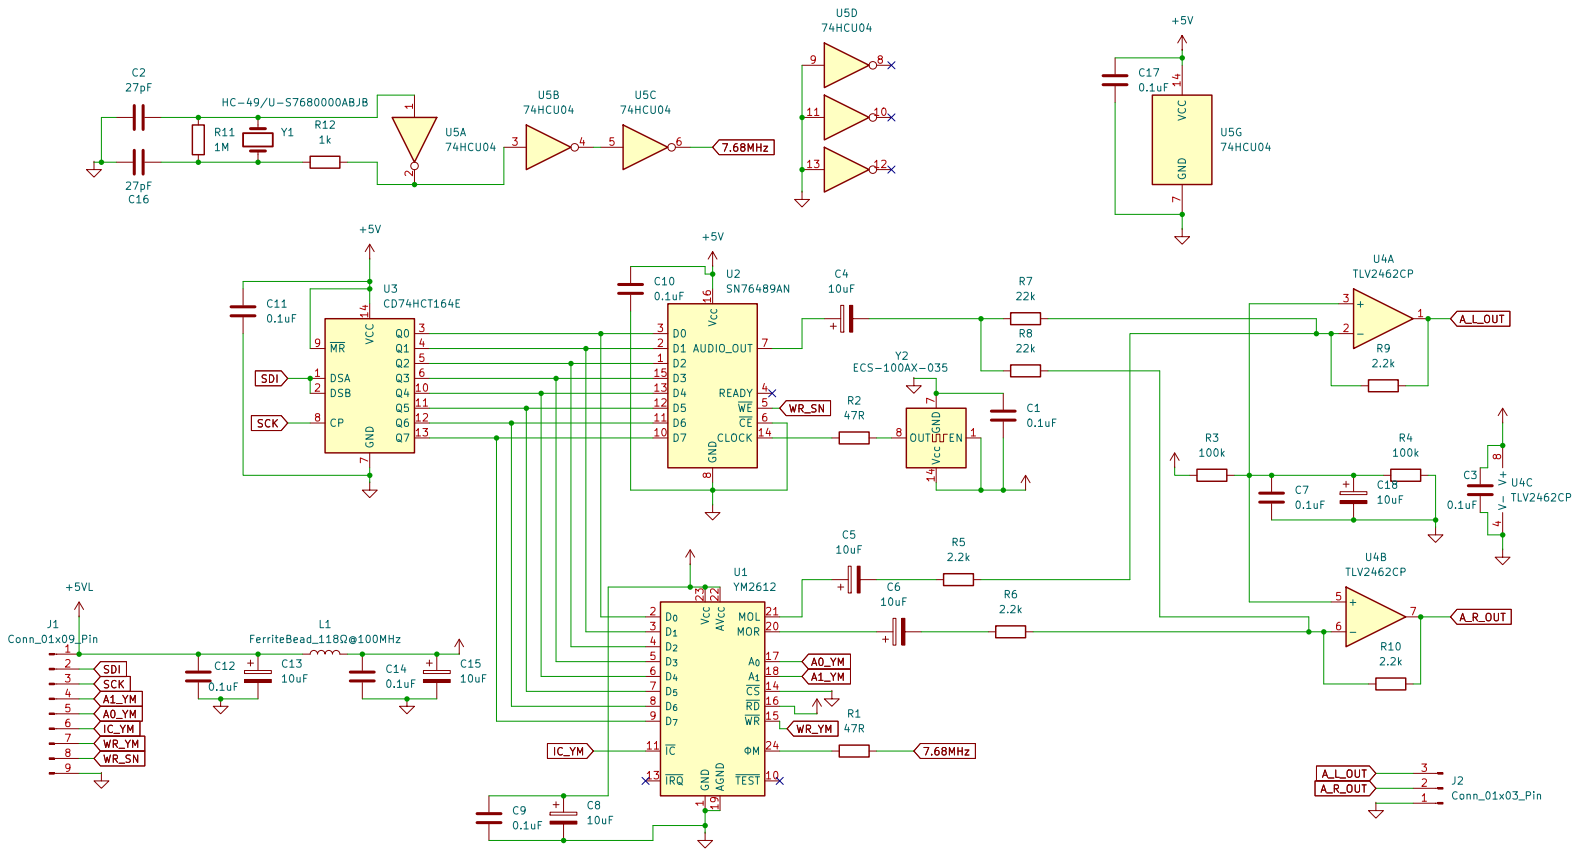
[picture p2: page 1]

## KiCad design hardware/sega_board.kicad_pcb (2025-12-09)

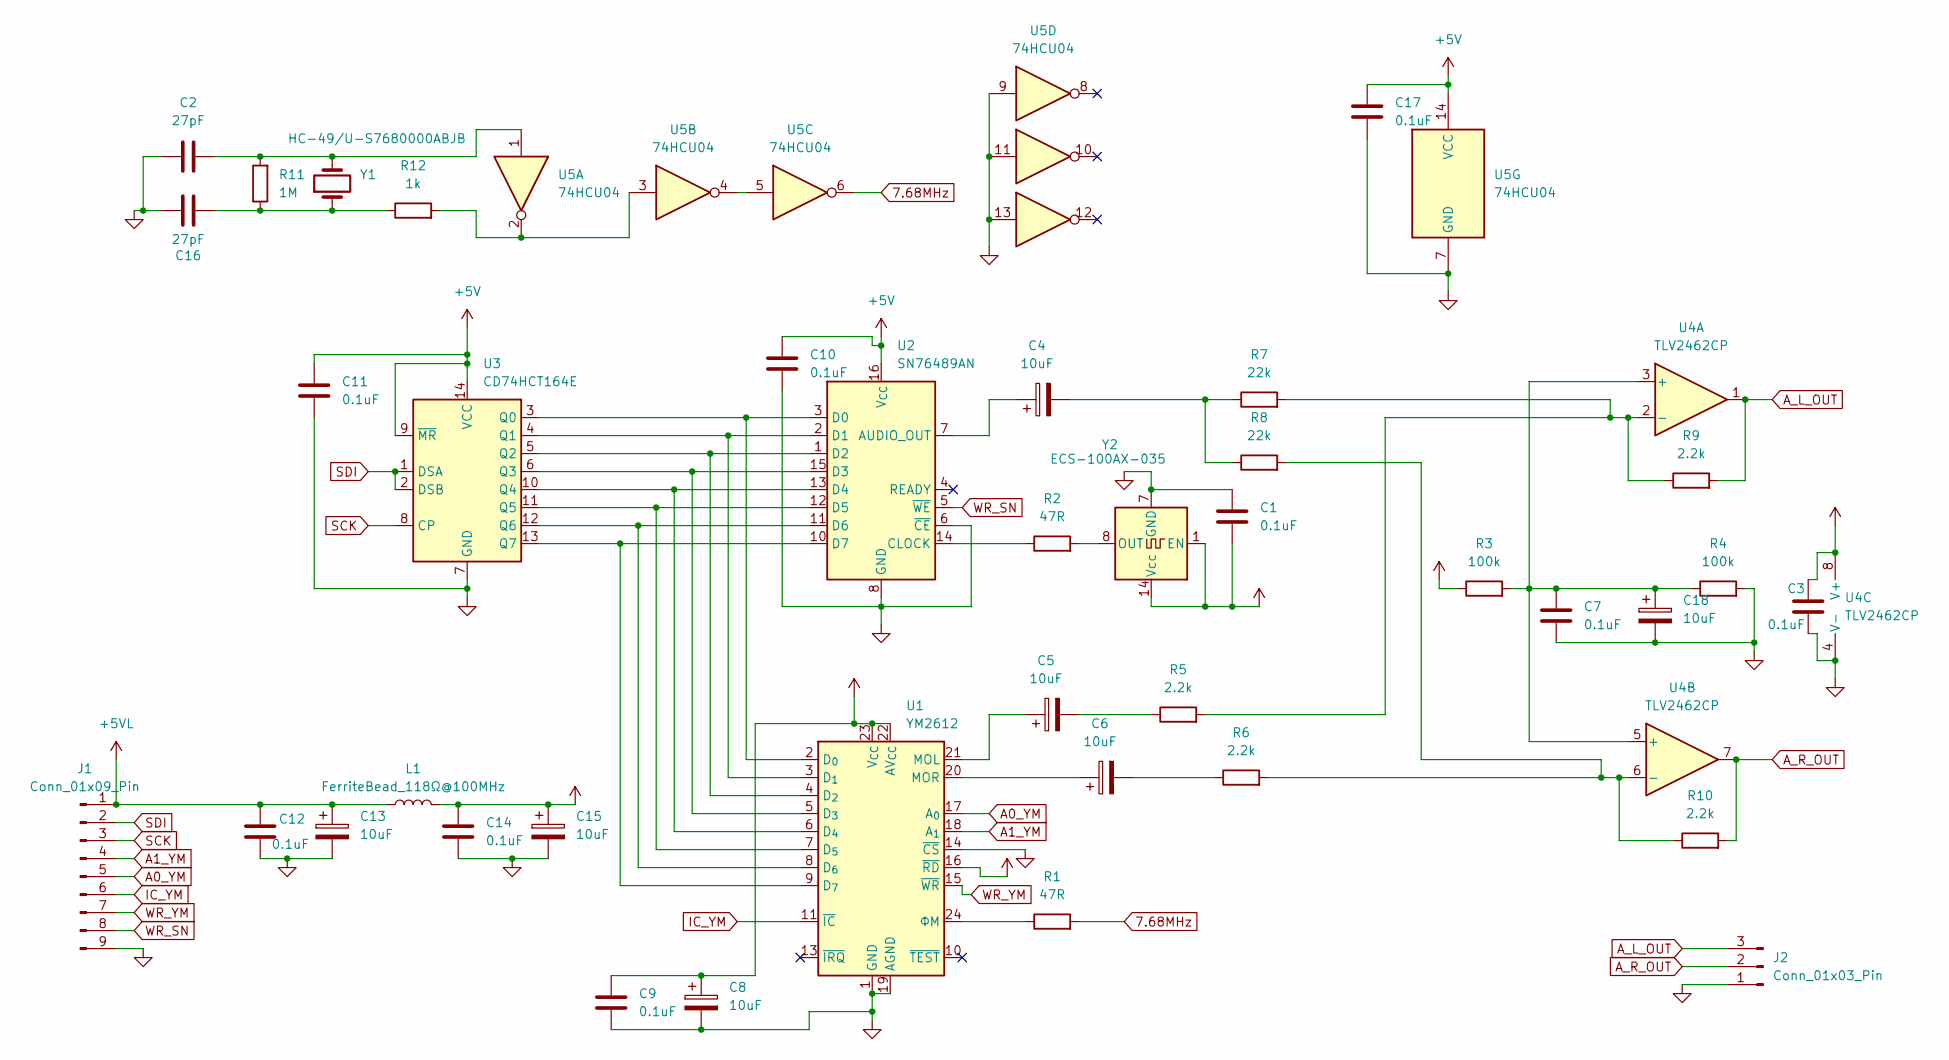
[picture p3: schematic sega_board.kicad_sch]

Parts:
C1, C3, C7, C9, C10, C11, C12, C14, C17: 0.1uF; C_Disc_D3.0mm_W1.6mm_P2.50mm
C2, C16: 27pF; C_Disc_D3.0mm_W1.6mm_P2.50mm
C4, C5, C6, C8, C13, C15, C18: 10uF; CP_Radial_D5.0mm_P2.00mm
J1: Conn_01x09_Pin; PinHeader_1x09_P2.54mm_Vertical
J2: Conn_01x03_Pin; PinHeader_1x03_P2.54mm_Vertical
L1: FerriteBead_118Ω@100MHz; R_Axial_DIN0207_L6.3mm_D2.5mm_P7.62mm_Horizontal; MPN 2743003112
R1, R2: 47R; R_Axial_DIN0207_L6.3mm_D2.5mm_P7.62mm_Horizontal
R3, R4: 100k; R_Axial_DIN0207_L6.3mm_D2.5mm_P7.62mm_Horizontal
R5, R6, R9, R10: 2.2k; R_Axial_DIN0207_L6.3mm_D2.5mm_P7.62mm_Horizontal
R7, R8: 22k; R_Axial_DIN0207_L6.3mm_D2.5mm_P7.62mm_Horizontal
R11: 1M; R_Axial_DIN0207_L6.3mm_D2.5mm_P7.62mm_Horizontal
R12: 1k; R_Axial_DIN0207_L6.3mm_D2.5mm_P7.62mm_Horizontal
U1: YM2612; DIP-24_W15.24mm
U2: SN76489AN; DIP-16_W7.62mm
U3: CD74HCT164E; DIP-14_W7.62mm
U4: TLV2462CP; DIP-8_W7.62mm
U5: 74HCU04; DIP-14_W7.62mm
Y1: HC-49/U-S7680000ABJB; Crystal_HC49-U_Vertical; MPN HC-49/U-S7680000ABJB
Y2: ECS-100AX-035; Oscillator_DIP-14

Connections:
7.68MHz: R1.2, U5.6
+5V: C1.2, C3.1, C8.1, C9.1, C10.1, C11.1, C14.1, C15.1, C17.1, L1.2, R3.1, U1.16 (~RD), U1.22 (AV_{CC}), U1.23 (V_{CC}), U2.16 (V_{CC}), U3.9 (~MR), U3.14 (VCC), U4.8 (V+), U5.14 (VCC), Y2.1 (EN), Y2.14 (Vcc)
+5VL: C12.1, C13.1, J1.1, L1.1
A0_YM: J1.5, U1.17 (A_{0})
A1_YM: J1.4, U1.18 (A_{1})
A_L_OUT: J2.3, R9.2, U4.1
A_R_OUT: J2.2, R10.2, U4.7
GND: C1.1, C2.1, C3.2, C7.2, C8.2, C9.2, C10.2, C11.2, C12.2, C13.2, C14.2, C15.2, C16.1, C17.2, C18.2, J1.9, J2.1, R4.2, U1.1 (GND), U1.12 (GND), U1.14 (~CS), U1.19 (AGND), U2.6 (~CE), U2.8 (GND), U3.7 (GND), U4.4 (V-), U5.7 (GND), U5.9, U5.11, U5.13, Y2.7 (GND)
IC_YM: J1.6, U1.11 (~IC)
unnamed: C2.2, R11.2, U5.1, Y1.2
unnamed: C4.2, R7.1, R8.1
unnamed: C5.2, R5.1
unnamed: C6.2, R6.1
unnamed: C16.2, R11.1, R12.1, Y1.1
unnamed: R12.2, U5.2, U5.3
unnamed: U1.2 (D_{0}), U2.3 (D0), U3.3 (Q0)
unnamed: U1.3 (D_{1}), U2.2 (D1), U3.4 (Q1)
unnamed: U1.4 (D_{2}), U2.1 (D2), U3.5 (Q2)
unnamed: U1.5 (D_{3}), U2.15 (D3), U3.6 (Q3)
unnamed: U1.6 (D_{4}), U2.13 (D4), U3.10 (Q4)
unnamed: U1.7 (D_{5}), U2.12 (D5), U3.11 (Q5)
unnamed: U1.8 (D_{6}), U2.11 (D6), U3.12 (Q6)
unnamed: U1.9 (D_{7}), U2.10 (D7), U3.13 (Q7)
unnamed: C5.1, U1.21 (MOL)
unnamed: C6.1, U1.20 (MOR)
unnamed: R1.1, U1.24 (ΦM)
unnamed: C4.1, U2.7 (AUDIO_OUT)
unnamed: R2.1, U2.14 (CLOCK)
unnamed: C7.1, C18.1, R3.2, R4.1, U4.3 (+), U4.5 (+)
unnamed: R5.2, R7.2, R9.1, U4.2 (-)
unnamed: R6.2, R8.2, R10.1, U4.6 (-)
unnamed: U5.4, U5.5
unnamed: R2.2, Y2.8 (OUT)
SCK: J1.3, U3.8 (CP)
SDI: J1.2, U3.1 (DSA), U3.2 (DSB)
WR_SN: J1.8, U2.5 (~WE)
WR_YM: J1.7, U1.15 (~WR)

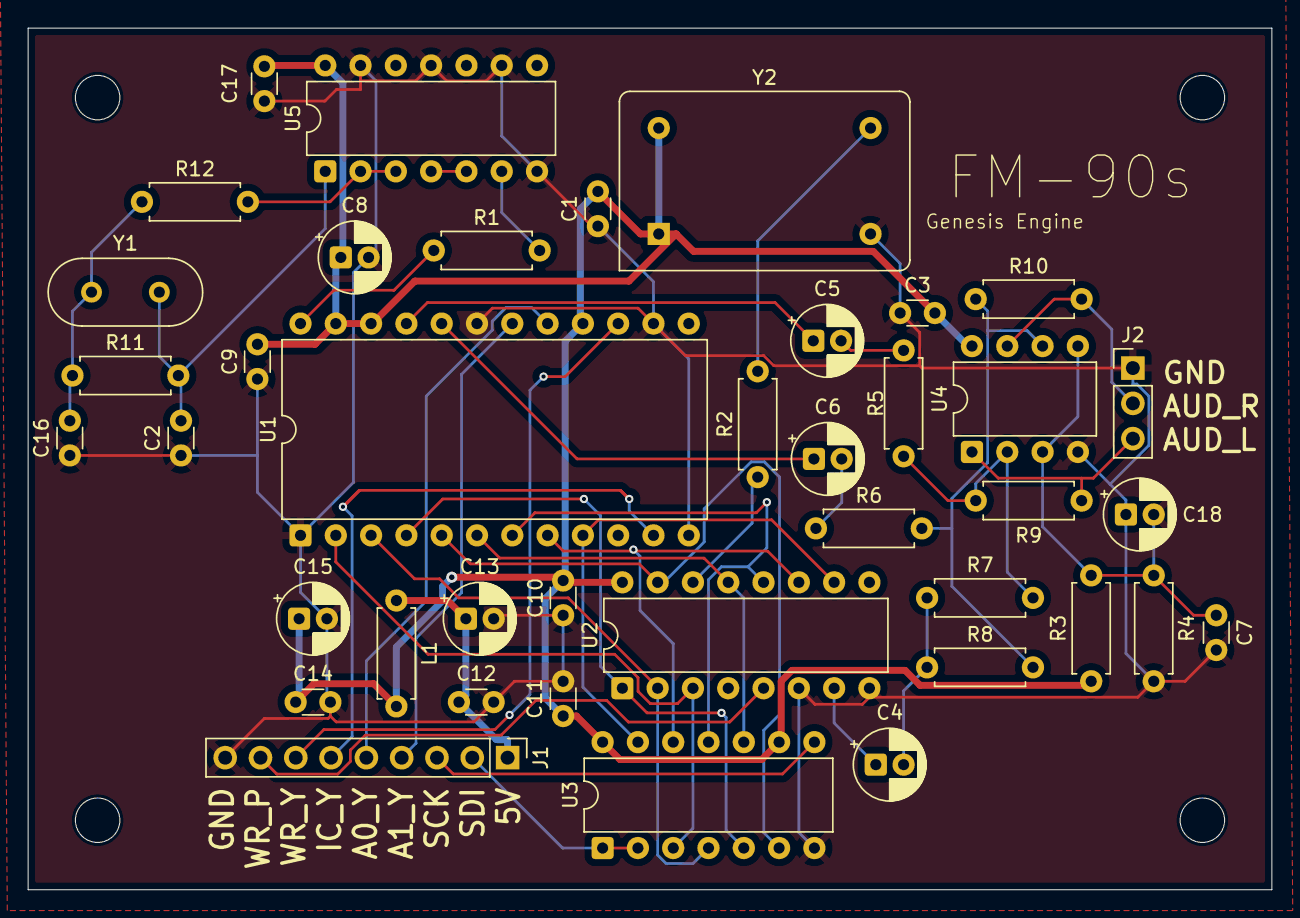
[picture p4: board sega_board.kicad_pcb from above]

Board: 2 copper layers, 89.5 x 62.0 mm, 44 parts (0 on the bottom side), 37 nets.

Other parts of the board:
H1, H2, H3, H4: MountingHole_3.2mm_M3

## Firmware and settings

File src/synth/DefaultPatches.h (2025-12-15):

#ifndef GENESIS_DEFAULT_PATCHES_H
#define GENESIS_DEFAULT_PATCHES_H

#include "FMPatch.h"
#include "PSGEnvelope.h"
#include "../config/platform_detect.h"

/**
 * Default FM Patches
 *
 * Classic Genesis-style sounds for immediate use.
 * These are stored in PROGMEM (flash memory) to save RAM.
 *
 * To use a patch, copy it to RAM first:
 *   FMPatch myPatch;
 *   memcpy_P(&myPatch, &defaultFMPatches[0], sizeof(FMPatch));
 *   FMPatch::loadToChannel(board, 0, myPatch);
 *
 * Patches:
 *   0: Bright EP (Electric Piano) - Algorithm 5
 *   1: Synth Bass - Algorithm 0
 *   2: Brass - Algorithm 4
 *   3: Lead Synth - Algorithm 7
 *   4: Organ - Algorithm 7
 *   5: Strings - Algorithm 2
 *   6: Pluck/Guitar - Algorithm 0
 *   7: Bell/Chime - Algorithm 4
 */
#define DEFAULT_FM_PATCH_COUNT 8
extern const FMPatch defaultFMPatches[DEFAULT_FM_PATCH_COUNT] GENESIS_PROGMEM;

/**
 * Default PSG Envelopes
 *
 * Software envelopes for SN76489 channels.
 * Update at 60Hz for proper timing.
 *
 * To use an envelope:
 *   PSGEnvelope myEnv;
 *   memcpy_P(&myEnv, &defaultPSGEnvelopes[0], sizeof(PSGEnvelope));
 *   state.trigger(&myEnv);
 *
 * Envelopes:
 *   0: Short pluck (quick decay, no loop) - ~170ms
 *   1: Sustain (organ-like, loops at full volume)
 *   2: Slow attack pad (fades in, loops sustain)
 *   3: Tremolo (volume wobble, loops)
 */
#define DEFAULT_PSG_ENV_COUNT 4
extern const PSGEnvelope defaultPSGEnvelopes[DEFAULT_PSG_ENV_COUNT] GENESIS_PROGMEM;

#endif // GENESIS_DEFAULT_PATCHES_H

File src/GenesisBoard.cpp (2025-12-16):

#include "GenesisBoard.h"
#include "config/feature_config.h"
#include <SPI.h>

#if defined(PLATFORM_ESP32)
#include "soc/gpio_struct.h"
// ESP32 runs at 240MHz = 4.17ns per cycle. A few NOPs provide sub-microsecond delays.
// 200ns ≈ 48 cycles, but function call overhead helps, so ~20 NOPs is enough
static inline void delayNanoseconds(uint32_t ns) __attribute__((always_inline));
static inline void delayNanoseconds(uint32_t ns) {
  if (ns < 50) return;  // Too short to matter
  // Each NOP is ~4ns at 240MHz. Rough approximation.
  uint32_t cycles = ns / 20;
  while (cycles--) { __asm__ __volatile__("nop"); }
}
#endif

// Use hardware SPI for shift register (much faster than bit-banging)
// Set to 0 to use software bit-banging on custom pins
// Automatically disabled on AVR/ESP32 when SD card support is enabled to avoid
// SPI bus conflict (shift register has no CS pin, would receive garbage
// during SD communication)
#if (defined(PLATFORM_AVR) || defined(PLATFORM_ESP32)) && GENESIS_ENGINE_USE_SD
  #define USE_HARDWARE_SPI 0
#else
  #define USE_HARDWARE_SPI 1
#endif

// =============================================================================
// YM2612 Register Definitions
// =============================================================================
static constexpr uint8_t YM2612_DAC_DATA   = 0x2A;  // DAC sample data register
static constexpr uint8_t YM2612_DAC_ENABLE = 0x2B;  // DAC enable (bit 7)

// =============================================================================
// Constructor
// =============================================================================
GenesisBoard::GenesisBoard(
  uint8_t pinWR_P,
  uint8_t pinWR_Y,
  uint8_t pinIC_Y,
  uint8_t pinA0_Y,
  uint8_t pinA1_Y,
  uint8_t pinSCK,
  uint8_t pinSDI
) :
  pinWR_P_(pinWR_P),
  pinWR_Y_(pinWR_Y),
  pinIC_Y_(pinIC_Y),
  pinA0_Y_(pinA0_Y),
  pinA1_Y_(pinA1_Y),
  pinSCK_(pinSCK),
  pinSDI_(pinSDI),
  lastWriteTime_(0),
  dacStreamMode_(false)
{
}

// =============================================================================
// Initialization
// =============================================================================
void GenesisBoard::begin() {
  // Configure control pins as outputs
  pinMode(pinWR_P_, OUTPUT);
  pinMode(pinWR_Y_, OUTPUT);
  pinMode(pinIC_Y_, OUTPUT);
  pinMode(pinA0_Y_, OUTPUT);
  pinMode(pinA1_Y_, OUTPUT);

  // Set initial states (active-low signals start HIGH)
  digitalWrite(pinWR_P_, HIGH);
  digitalWrite(pinWR_Y_, HIGH);
  digitalWrite(pinIC_Y_, HIGH);  // Not in reset
  digitalWrite(pinA0_Y_, LOW);
  digitalWrite(pinA1_Y_, LOW);

#if USE_HARDWARE_SPI
  // Use hardware SPI for shift register - MUCH faster
  // Mega: MOSI=51, SCK=52. Uno: MOSI=11, SCK=13
  SPI.begin();
  // 8MHz SPI clock - fast but within CD74HCT164E specs
  SPI.beginTransaction(SPISettings(8000000, MSBFIRST, SPI_MODE0));
#else
  // Software bit-bang on custom pins
  pinMode(pinSCK_, OUTPUT);
  pinMode(pinSDI_, OUTPUT);
  digitalWrite(pinSCK_, LOW);
  digitalWrite(pinSDI_, LOW);
#endif

  // Initialize fast GPIO for control pins
  initFastGPIO();

  // Give chips time to stabilize after power-on before reset
  // Teensy boots very fast, need longer delay for YM2612/PSG to be ready
  delay(200);

  // Reset both chips
  reset();

  lastWriteTime_ = micros();
}

// =============================================================================
// Reset
// =============================================================================
void GenesisBoard::reset() {
  // Reset YM2612 (hold IC low for at least 24 clock cycles)
  digitalWrite(pinIC_Y_, LOW);
  delayMicroseconds(500);  // Extended reset pulse for reliability
  digitalWrite(pinIC_Y_, HIGH);
  delayMicroseconds(500);  // Wait for chip to stabilize

  // Silence PSG
  silencePSG();

  dacStreamMode_ = false;
  lastWriteTime_ = micros();
}

// =============================================================================
// YM2612 Functions
// =============================================================================

void GenesisBoard::writeYM2612(uint8_t port, uint8_t reg, uint8_t val) {
  // Exit DAC stream mode if active
  if (dacStreamMode_) {
    endDACStream();
  }

#if defined(PLATFORM_AVR)
  // AVR: GPIO is slow enough, no need for busy wait or time tracking
  // Set port select (A1)
  if (port) *portA1_Y_ |= maskA1_Y_; else *portA1_Y_ &= ~maskA1_Y_;

  // Address phase: A0 low
  *portA0_Y_ &= ~maskA0_Y_;
  shiftOut8(reg);
  // Pulse WR low
  *portWR_Y_ &= ~maskWR_Y_;
  *portWR_Y_ |= maskWR_Y_;

  // Data phase: A0 high
  *portA0_Y_ |= maskA0_Y_;
  shiftOut8(val);
  // Pulse WR low
  *portWR_Y_ &= ~maskWR_Y_;
  *portWR_Y_ |= maskWR_Y_;
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

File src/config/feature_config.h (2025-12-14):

#ifndef GENESIS_ENGINE_FEATURE_CONFIG_H
#define GENESIS_ENGINE_FEATURE_CONFIG_H

#include "platform_detect.h"

// =============================================================================
// Feature Configuration
// Features are auto-enabled based on platform, but can be overridden
// =============================================================================

// -----------------------------------------------------------------------------
// SD Card Support
// Auto-enabled when SD.h library is available (detected via __has_include)
// -----------------------------------------------------------------------------
#ifndef GENESIS_ENGINE_DISABLE_SD
  #if __has_include(<SD.h>)
    #define GENESIS_ENGINE_USE_SD 1
  #endif
#endif

// Ensure GENESIS_ENGINE_USE_SD is defined (as 0) if not enabled
#ifndef GENESIS_ENGINE_USE_SD
  #define GENESIS_ENGINE_USE_SD 0
#endif

// SD Card chip select pin (platform-specific defaults)
#ifndef GENESIS_ENGINE_SD_CS_PIN
  #if defined(PLATFORM_TEENSY4) || defined(PLATFORM_TEENSY3)
    #define GENESIS_ENGINE_SD_CS_PIN BUILTIN_SDCARD
  #elif defined(PLATFORM_AVR) && defined(__AVR_ATmega2560__)
    #define GENESIS_ENGINE_SD_CS_PIN 53  // Mega default
  #elif defined(PLATFORM_AVR)
    #define GENESIS_ENGINE_SD_CS_PIN 10  // Uno default
  #elif defined(PLATFORM_ESP32)
    #define GENESIS_ENGINE_SD_CS_PIN 5   // Common ESP32 default
  #else
    #define GENESIS_ENGINE_SD_CS_PIN 10  // Generic default
  #endif
#endif

// -----------------------------------------------------------------------------
// VGZ Decompression (gzip)
// Only on platforms with enough RAM for decompression buffer (~45KB)
// -----------------------------------------------------------------------------
#ifndef GENESIS_ENGINE_DISABLE_VGZ
  #if defined(PLATFORM_TEENSY4) || defined(PLATFORM_TEENSY3) || \
      defined(PLATFORM_ESP32) || defined(PLATFORM_RP2040)
    #define GENESIS_ENGINE_USE_VGZ 1
  #endif
#endif

// Ensure GENESIS_ENGINE_USE_VGZ is defined (as 0) if not enabled
#ifndef GENESIS_ENGINE_USE_VGZ
  #define GENESIS_ENGINE_USE_VGZ 0
#endif

// -----------------------------------------------------------------------------
// USB MIDI Support
// Only on Teensy (native USB MIDI)
// -----------------------------------------------------------------------------
#ifndef GENESIS_ENGINE_DISABLE_MIDI
  #if defined(PLATFORM_TEENSY4) || defined(PLATFORM_TEENSY3)
    #define GENESIS_ENGINE_USE_MIDI 1
  #endif
#endif

// -----------------------------------------------------------------------------
// DAC Pre-render Support
// Only on Teensy with Audio Board capability
// -----------------------------------------------------------------------------
#ifndef GENESIS_ENGINE_DISABLE_DAC_PRERENDER
  #if defined(PLATFORM_TEENSY4) || defined(PLATFORM_TEENSY3)
    #define GENESIS_ENGINE_USE_DAC_PRERENDER 1
  #endif
#endif

// -----------------------------------------------------------------------------
// Timer-based Accurate Timing
// Uses IntervalTimer on Teensy for sample-accurate playback
// -----------------------------------------------------------------------------
#if PLATFORM_HAS_INTERVAL_TIMER
  #define GENESIS_ENGINE_USE_TIMER 1
#else
  #define GENESIS_ENGINE_USE_TIMER 0
#endif

// -----------------------------------------------------------------------------
// Buffer Sizes
// Larger buffers on platforms with more RAM
// -----------------------------------------------------------------------------
#ifndef GENESIS_ENGINE_BUFFER_SIZE
  #if defined(PLATFORM_TEENSY4)
    #define GENESIS_ENGINE_BUFFER_SIZE 8192
  #elif defined(PLATFORM_TEENSY3) || defined(PLATFORM_ESP32)
    #define GENESIS_ENGINE_BUFFER_SIZE 4096
  #elif defined(PLATFORM_RP2040) || defined(PLATFORM_SAM)
    #define GENESIS_ENGINE_BUFFER_SIZE 2048
  #elif defined(PLATFORM_AVR) && defined(__AVR_ATmega2560__)
    #define GENESIS_ENGINE_BUFFER_SIZE 512
  #else
    #define GENESIS_ENGINE_BUFFER_SIZE 256
  #endif
#endif

// -----------------------------------------------------------------------------
// Maximum VGM File Size for PROGMEM
// Used by the converter tool to warn about large files
// -----------------------------------------------------------------------------
#if defined(PLATFORM_AVR)
  #if defined(__AVR_ATmega2560__)
    #define GENESIS_ENGINE_MAX_PROGMEM (256UL * 1024UL - 8192UL)  // 248KB
  #else
    #define GENESIS_ENGINE_MAX_PROGMEM (32UL * 1024UL - 4096UL)   // 28KB
  #endif
#else
  #define GENESIS_ENGINE_MAX_PROGMEM (1024UL * 1024UL)  // 1MB (arbitrary limit)
#endif
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

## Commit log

2025-12-07 Fix buffer overflow bug - NAK when buffer full instead of dropping bytes
    [SerialStreaming.ino, stream_vgm.py]
2025-12-07 Shorter timeouts in receiveChunk for better playback timing
    [SerialStreaming.ino, stream_vgm.py]
2025-12-08 Binary protocol with non-blocking playback and flow control
    - Add StreamingProtocol.h with command definitions
    - Use micros()-based non-blocking timing instead of delay()
    - Chunked protocol with checksum for data integrity
    - Flow control: READY signal when buffer has room
    - Support for RLE wait compression and DPCM DAC compression
    - Playback prioritized over chunk reception in main loop
2025-12-08 Optimize streaming with larger buffers, non-blocking receive, and DAC options
    Arduino:
    - Larger buffers: Uno 512B, Mega 2KB (was 256/512)
    - 75% buffer fill before playback starts
    - Fully non-blocking state machine for receiving chunks
    - Pipelined ACKs during playback, immediate ACKs during buffering
    - Fixed DAC command conflict (removed unused CMD_DAC_DATA_BLOCK)
    Python:
    - Pipelined chunk sending (3 chunks in flight)
    - Wait optimization: merges consecutive waits, uses RLE for frame-aligned waits
    - DAC compression options: --dac-rate, --dac-bits, --dpcm
    - New --no-dac option to strip DAC completely (FM/PSG only)
    - NAK handling to prevent deadlocks
    [SerialStreaming.ino, stream_vgm.py]
2025-12-08 Fast GPIO and protocol fixes for reliable streaming
    - Fix flow control conflict: FLOW_READY/NAK now use 0x06/0x15 instead of
    'R'/'N' which conflicted with YM2612 command 0x52
    - Add direct port manipulation for shiftOut8() - ~20x faster on AVR
    - Platform-specific optimizations for AVR, Teensy 3/4, ESP32
    - Reduce baud to 250000 for reliability
    - Add PING/ACK handshake before streaming
    - Reset chips before playback starts
    - Simplify flow control and retransmit logic
    [GenesisBoard.cpp, GenesisBoard.h, SerialStreaming.ino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]
2025-12-08 Fast ring buffer with bitmask modulo, fast GPIO for all control pins
    - Replace modulo (%) with bitmask (&) for ring buffer operations
    AVR has no hardware division, bitmask is much faster
    - Extend fast GPIO to all control pins (WR_Y, WR_P, A0_Y, A1_Y)
    - Platform-specific timing: AVR doesn't need YM_BUSY delays
    (GPIO is slow enough naturally), Teensy still needs them
    - PSG requires 8us pulse width on all platforms
    - Multi-command processing loop with interleaved serial reads
    [GenesisBoard.cpp, GenesisBoard.h, SerialStreaming.ino]
2025-12-08 Hardware SPI for shift register, optimized timing calculations
    - Use hardware SPI instead of bit-banging (~1us vs ~20us per byte)
    Mega: MOSI=51, SCK=52. Uno: MOSI=11, SCK=13
    - Replace division with multiplication for sample-to-microsecond conversion
    samples * 23 approximates samples * 1000000 / 44100 (< 1.5% error)
    - Branchless bufferAvailable() using bitmask
    - Process 8 commands between serial checks (was 4)
    - Added pin reference table for all supported boards
    [GenesisBoard.cpp, SerialStreaming.ino]
2025-12-08 Smart timing catch-up, 500k baud, process 16 commands per serial check
    - Add smart wait timing: accumulate from scheduled time, snap to now if behind
    - Increase baud to 500000 for higher throughput
    - Process 16 commands between serial checks (was 8)
    - Eliminates jitter and tempo drift during DAC-heavy playback
    [SerialStreaming.ino, stream_vgm.py]
2025-12-08 Remove unused DPCM and dac-bits options, simplify DAC processing
    - Remove --dpcm flag (didn't help throughput, added CPU overhead)
    - Remove --dac-bits flag (didn't reduce command count)
    - Keep --dac-rate (directly reduces command count, the real bottleneck)
    - Simplify protocol and command processing
    [SerialStreaming.ino, stream_vgm.py]
2025-12-08 Uno support with known startup limitation
    - Uno works with same code as Mega
    - Smaller buffers for Uno (512 ring, 128 serial) in platformio.ini
    - Known issue: Uno may have retransmits at startup while finding
    equilibrium, then plays perfectly once stabilized
    - Hardware SPI pins: Uno uses MOSI=11, SCK=13
    [SerialStreaming.ino]
2025-12-08 Add VGM looping support with native loop point detection
    - Parse VGM loop offset (0x1C) and loop samples (0x20) from header
    - Track loop point index through all preprocessing stages
    - Support --loop for infinite looping, --loop N for N plays
    - Seamless loop transitions without waiting for pending ACKs
    - Honor native VGM loop points when present, restart from beginning otherwise
2025-12-08 Fix end-of-stream handling and clear hanging notes
    - Arduino flushes all pending ACKs when receiving CHUNK_END
    - Python no longer waits for pending ACKs before sending CHUNK_END
    - Use board.reset() instead of muteAll() to clear hanging notes on stop
    [SerialStreaming.ino, stream_vgm.py]
2025-12-08 Board-specific flow control settings, Arduino announces board type
    - Arduino sends BOARD_TYPE during handshake
    - Python uses board-specific chunk size and chunks-in-flight
    - Uno: 64-byte chunks, 1 in-flight (fixes buffer overflow during initial fill)
    - Mega: 128-byte chunks, 3 in-flight
    - Added debug stats for chunks sent vs NAKs
    [SerialStreaming.ino, stream_vgm.py]
2025-12-08 Increase baud to 1Mbaud, auto DAC rate per board type
    - Increase serial baud rate from 500k to 1M (both Arduino and Python)
    - Add board-specific default DAC rate (Uno/Mega: 1/4, others: full)
    - DAC processing deferred until board type is known from handshake
    - Add --dac-rate 3 option for finer control
    - Fix looping: wait for pending chunks to drain before loop transition
    - Mega uses 1 chunk in flight to match Uno for consistent behavior
    [SerialStreaming.ino, stream_vgm.py]
2025-12-08 Teensy 4.x support with proper chip timing
    - Add Teensy 4.x board detection and settings (BOARD_TYPE 4)
    - Add 4us data setup time and 200ns WR pulse for FM writes on Teensy/ESP32
    - Add 100ns data setup + 200ns WR pulse for DAC writes on Teensy/ESP32
    - PING now resets everything, allowing reconnection after Ctrl+C
    - Extend reset pulse to 500us and add 50ms power-on delay for reliability
    - All boards now use 1 chunk in flight for consistent behavior
    [GenesisBoard.cpp, SerialStreaming.ino, stream_vgm.py]
2025-12-08 Clean up comments and generalize board references
    - Rewrite SerialStreaming.ino header with clear pin connections and usage
    - Change Arduino-specific references to generic device/board terminology
    - Add ESP32 to supported boards list and SPI pin table
    - Update StreamingProtocol.h comments for consistency
2025-12-08 Auto-attenuate PSG when playing FM+PSG mix
    - Detect if VGM uses both YM2612 and PSG
    - When both present, reduce PSG volume by 2 steps to balance mix
    - PSG-only songs (Game Gear) play at full volume
    - Cap attenuation at 14 to preserve quiet sounds (15 = silent)
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2025-12-09 Add vgm_prep.py tool, fix DAC downsampling timing
    - Add vgm_prep.py: converts VGZ to VGM with inlined DAC samples
    - Default 1/4 DAC rate for Uno/Mega compatibility
    - Use --dac-rate 1 for full quality on faster boards
    - Preserves loop points, no RAM needed for PCM storage
    - Fix PCMDataBank downsampling: repeat samples to maintain timing
    (was playing 4x too fast when downsampled)
    - Add clear VGZ error message on unsupported platforms with
    instructions to use vgm_prep.py
    - Add RAM simulation flags for testing memory-constrained behavior
    - Update SDCardPlayer docs with vgm_prep.py usage for Uno/Mega
    [PCMDataBank.cpp, SDCardPlayer.ino, feature_config.h]
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2025-12-09 Add README, LICENSE, and hardware files for public release
    - Add README with project overview, wiring guide, and usage examples
    - Add LGPL-2.1 LICENSE
    - Add KiCad schematic and PCB files in hardware/
    - Update .gitignore for VGM files, Python cache, and KiCad artifacts
    - Clean up unused test files
    [sega_board.kicad_pcb, sega_board.kicad_sch]
2025-12-09 Fix README examples with proper pin definitions
2025-12-09 Add MIDISynth example for USB MIDI synthesizer
    Turn GenesisEngine into a USB MIDI synthesizer with:
    - 6 FM channels (YM2612) on MIDI Ch 1-6
    - 3 PSG tone + 1 noise channel on MIDI Ch 7-10
    - 16 FM patch slots, 8 PSG envelope slots
    - Multi-timbral mode (default) or 6-voice poly mode
    - Voice allocation with oldest-note stealing in poly mode
    - Velocity sensitivity, pitch bend, vibrato (LFO)
    - Real-time CC control of FM parameters
    - SysEx patch loading via Python companion tool
    - Support for TFI, DMP, and GYB patch formats
    - 8 built-in FM patches and 4 PSG envelopes
    [DefaultPatches.h, MIDISynth.ino]
2025-12-10 Fix DAC audio - pace writes to prevent sample loss
    When batched data arrives, multiple DAC writes could execute
    back-to-back with only ~5µs between them. But YM2612 DAC at
    22kHz needs ~45µs between samples or values get overwritten
    before the chip's internal sample tick captures them.
    - Add 45µs minimum spacing between DAC writes
    - Use fast writeDAC() path for register 0x2A
    - Fix PING handling to only trigger when not connected
    - Simplify ring buffer and command processing
    [EmulatorBridge.ino]
2025-12-10 Implement VGM-style protocol for accurate DAC timing
    - Parse VGM wait commands (0x61, 0x62, 0x63, 0x70-0x7F) instead of delta prefixes
    - Fix buffer overflow bug that was corrupting commands when buffer full
    - Add snap-to-now logic to prevent playing too fast when catching up
    - Fix PING handling to not trigger on 0x00 data bytes
    - Accumulate wait times for drift-free timing
    [EmulatorBridge.ino]
2025-12-10 Reset timing on END_STREAM for clean ROM transitions
    - Reset targetTime when END_STREAM received
    - Ensures timing starts fresh after emulator reset/ROM change
    [EmulatorBridge.ino]
2025-12-10 Fix false PING detection causing audio resets
    - Change PING byte from 0x00 to 0xAA (0x00 appeared in DAC samples)
    - Only check for PING when not connected
    - END_STREAM resets hardware but stays connected
    - Disable timeout (was firing during ROM load gaps)
    [EmulatorBridge.ino]
2025-12-11 Detect USB disconnect and reset connection state
    [EmulatorBridge.ino]
2025-12-11 MIDISynth: Fix poly mode velocity and add mode switching
    - Fix poly mode velocity bug: update fmChannelPatch[] when entering
    poly mode so velocity calculations use correct patch TL values
    - Fix poly mode patch loading: update all 6 channels when loading
    a patch in poly mode via SysEx
    - Add poly/multi commands to genesis_patch.py for easy mode switching
    - Change user-facing numbers to 1-based (channels 1-6, slots 1-16)
    to match DAW conventions
    - Update platformio.ini for MIDISynth with USB_MIDI_SERIAL
    [MIDISynth.ino]
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2025-12-13 BasicPlayback: Fix PROGMEM loop seeking and improve vgm2header.py
    - Fix loop point seeking for PROGMEM playback by adding setDataStart()
    to ProgmemSource, matching SDSource behavior
    - vgm2header.py: Use PROGMEM for all platforms (fixes Teensy flash placement)
    - vgm2header.py: Fix loop offset when using --strip-dac
    - vgm2header.py: Update platform size limits to be more practical
    - Add README with usage instructions
    [BasicPlayback.ino]
2025-12-14 SerialStreaming: Fix protocol edge cases and improve timing accuracy
    - Send NAK on invalid chunk length (prevents Python from hanging)
    - Use accurate timing on Teensy 4.x (eliminates 1.4% drift)
    - Rename RX_READING_DATA to RX_AWAITING_CHECKSUM for clarity
    - Remove unused commandsProcessed variable
    - Update comment paths to reflect moved script location
    [SerialStreaming.ino]
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2025-12-14 Fix SDSource position/seek mismatch causing DAC playback glitches
    SDSource::position() was returning absolute file position while seek()
    expected relative positions. This caused skip() to double-add the data
    offset, misaligning the command stream during DAC-heavy playback.
    Also fixes:
    - Handle 0-byte PCM data blocks (some VGM files have these)
    - AVR compatibility for PCMDataBank allocation (use malloc)
    - Remove noisy data block debug output
    [PCMDataBank.cpp]
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2025-12-14 EmulatorBridge: Replace BLASTEM_INTEGRATION.md with comprehensive README
    New documentation covers quick start, board compatibility, troubleshooting,
    and technical details including protocol, handshake, and timing architecture.
2025-12-14 Cleanup: Remove GEP format files and obsolete tools
    - Remove GEP sample files (greenhill_gep.h, sonic_gg.h)
    - Add greenhill.h as VGM-based replacement sample
    - Remove vgm2header.py (superseded by vgm_prep.py)
    - Update platformio.ini: remove GEP reference, set default to MIDISynth
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2025-12-14 Config: Auto-detect SD library, reduce Uno VGM limit
    - SD support now uses __has_include(<SD.h>) to auto-detect if library
    is available, fixing compilation errors on platforms without SD
    - Reduced Uno VGM size limit from 24KB to 16KB to account for
    GenesisEngine library overhead (~14KB)
    [feature_config.h]
2025-12-14 SDCardPlayer: Add Mega support, drop Uno due to RAM limits
    - Disable hardware SPI on AVR when SD enabled (shift register conflicts)
    - Add mega_sd environment to platformio.ini for SD card testing
    - Update documentation: Uno not supported, Mega limited, Teensy recommended
    - Fix vgm_prep.py path references in error messages
    [GenesisBoard.cpp, SDCardPlayer.ino]
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2025-12-15 ESP32: Fix compilation and PSG timing issues
    - Add delayNanoseconds shim (ESP32 doesn't have this Teensy function)
    - Fix PSG write pulse timing: 4µs → 8µs (SN76489 needs full pulse)
    - Add ESP32 free memory detection using heap_caps_get_free_size()
    - Fix VGZSource to require both VGZ and SD (avoid SD.h when not needed)
    - Add ESP32-specific pin defaults avoiding boot/flash conflicts
    - Update README with ESP32 wiring table and GPIO warnings
    Tested on ESP32-DevKitC-32E (WROOM-32E module).
    [BasicPlayback.ino, GenesisBoard.cpp, PCMDataBank.cpp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]
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2025-12-16 Fix SimpleSynth serial input, add ESP32 pins to examples
    SimpleSynth: Replace Serial.parseInt() with line-based input.
    The parseInt() function has a 1-second blocking timeout that made
    commands execute immediately. Now uses buffered input with echo
    and waits for Enter key before processing.
    EmulatorBridge, SDCardPlayer: Add ESP32 pin configuration
    matching BasicPlayback and other examples.
    [EmulatorBridge.ino, SDCardPlayer.ino, SimpleSynth.ino]
2025-12-16 Fix ESP32 serial streaming timing issues
    ESP32's Arduino Serial implementation has significant per-byte overhead
    due to FreeRTOS queue operations. This caused slow playback tempo,
    especially during DAC-heavy sections.
    Fixes:
    - Add bulk serial reads using Serial.readBytes() with local buffer
    - Set Serial.setTimeout(0) for non-blocking reads
    - Disable yield() during playback (causes FreeRTOS context switches)
    - Increase RX buffer from 1024 to 4096
    - Increase chunk size from 32 to 128 (matching Teensy)
    - Use fast timing approximation (samples * 23) instead of division
    - Add ESP32 board type detection in Python script
    [SerialStreaming.ino, stream_vgm.py]
2025-12-16 Fix ESP32 serial timing in EmulatorBridge
    - Set Serial.setRxBufferSize(4096) and setTimeout(0) for non-blocking
    - Fix ESP32 detection macro consistency (ARDUINO_ARCH_ESP32)
    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
    [EmulatorBridge.ino]
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2025-12-16 Add 3D printable stand, minor cleanups
    - Add Stand.stl for 3D printing a board stand
    - Simplify SimpleSynth README
    - KiCad project file updates
    [Stand.stl]
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2025-12-22 Fix visualization sync by decoupling sample generation from commands
    Redesigned CommandInterceptor with two separate threads:
    - Command thread: applies chip writes immediately (fast, no blocking)
    - Sample thread: generates samples at constant 60fps rate
    This fixes the 10-15 second visualization delay that occurred when
    command processing couldn't keep up with real-time playback.
    Also re-enabled Furnace-style phase-locked waveform display with:
    - FFT-based autocorrelation for period detection
    - DFT phase detection for stable triggering
    - Smoothed needle position to prevent jumping
    - Auto-scaling amplitude for quiet signals
2025-12-22 Fix visualization sync with wall-clock synchronized playback
    Replaced async queue-based architecture with parallel real-time design:
    - Visualization thread runs independently at real-time rate
    - Both hardware streaming and visualization start at same moment
    - Both process commands at 44100 Hz rate based on wall clock
    - Eliminates queue lag that caused 10-15 second desync
    Key changes:
    - CommandInterceptor now processes commands synchronously (no queues)
    - VisualStreamer preprocesses VGM and runs viz thread in parallel
    - Added start_callback to signal when streaming begins
    [stream_vgm_visual.py]
2025-12-22 Add accurate YM2612 emulator and Furnace-style phase-locked display
    - Replace placeholder YM2612 emulator with Genesis Plus GX-based implementation
    featuring proper envelope generator, sine/power tables, and FM algorithms
    - Implement Furnace-style autocorrelation pitch detection for waveform triggering
    - Add phase-locked needle positioning for stable oscilloscope display
    - Improve SN76489 with proper LFSR noise generator
    - Add auto-gain scaling with amplitude smoothing
2025-12-22 Improve oscilloscope trigger with frame-continuous tracking and shape matching
    - Track trigger position as offset from buffer end for stability
    - Advance trigger by samples received each frame for smooth scrolling
    - Snap to nearest rising zero crossing for consistent phase
    - When jumping (after drift), use waveform shape matching to find
    similar-looking crossing point, preventing flickering between phases
    - Compare 32-sample templates with normalized correlation (threshold 0.5)
2025-12-22 Add piano keyboard visualization with pitch tracking and visual enhancements
    - Add vertical piano keyboard with proper white/black key layout
    - Track FM and PSG pitch from register writes for floating note indicators
    - Support fractional pitch display for pitch bends and vibrato
    - Add 90s neon color scheme (hot pink, neon orange, hacker green, etc.)
    - Add smooth gradient glow effect on waveforms based on amplitude
    - DAC mode detection - FM6 scrolls when DAC enabled, triggers when FM
    - Indicator glow transitions smoothly while line/circle appear instantly
    - Pure white center lines on oscilloscope plots
    - ymfm binding with per-channel output and DAC state access
    [stream_vgm_visual.py]
2025-12-22 Add pygame + OpenGL visualizer with CRT shader effects
    - New app_pygame.py with OpenGL rendering and GLSL shaders
    - CRT effects: barrel distortion, scanlines, phosphor mask, bloom
    - Amplitude-based zoom/pulse effect (applied before CRT so scanlines stay fixed)
    - Gradient glow effect on active channels using additive blending
    - Scissor clipping to prevent waveforms from spilling outside boxes
    - Same waveform triggering/stabilization logic as imgui version
    - DAC label switching when FM6 is in DAC mode
    - Toggle between pygame and imgui versions via _USE_PYGAME flag
    [stream_vgm_visual.py]
2025-12-22 Add resizable window and fullscreen support with 4:3 letterboxing
    - Window can be resized by dragging borders
    - F11 toggles fullscreen mode with 4:3 aspect ratio letterboxing
    - ESC exits fullscreen (or closes app if windowed)
    - Uses Windows API to detect correct monitor and physical resolution
    - Properly handles multi-monitor setups and DPI scaling
    - Framebuffers resize dynamically to match window/viewport size
2025-12-23 Add visualization loop support and improve DAC/noise display
    - Fix visualization to loop with audio playback
    - Increase DAC/noise time window to 4096 samples for better display
    - Add downsampling for scrolling channels to maintain performance
    - Fix DAC channel to show glow when active
    - Remove thick DAC line width
    [stream_vgm_visual.py]
2025-12-23 Improve visualization sync with skip-to-catchup and loop fix
    - Pre-calculate cumulative sample times for fast seeking
    - Skip commands (not just waits) when more than 25ms behind
    - Use binary search to find correct command for current time
    - Fix loop handling by adjusting time reference on loop
    - Add 200ms sync offset to compensate for hardware buffer
    [stream_vgm_visual.py]
2025-12-23 Tighten visualization sync with bidirectional 10ms threshold
    - Remove hardcoded 200ms sync offset - let catch-up handle it
    - Tighten drift threshold from 25ms to 10ms
    - Add bidirectional sync: skip ahead if behind, wait if ahead
    [stream_vgm_visual.py]
2025-12-23 Fix sync catch-up and add adaptive display for low frequencies
    - Fix catch-up sync: process all commands through interceptor, only skip sleep
    (skipping commands entirely broke emulator state and caused blank waveforms)
    - Add adaptive display samples based on channel pitch
    - Normal frequencies: keep default 256 samples to show frequency changes
    - Low frequencies: expand window to show ~1.5 cycles (up to 1024 samples)
    [stream_vgm_visual.py]
2025-12-23 Add --no-crt CLI option to disable CRT shader effects
    CRT filter is on by default but can be disabled with --no-crt flag.
    Uses passthrough shader when CRT is disabled instead of fixed-function
    OpenGL which has matrix setup issues.
    [stream_vgm_visual.py]
2025-12-24 Improve offline audio mode performance from 30-40 to 60 FPS
    - Disable bloom sampling in CRT shader (14 -> 3 texture samples/pixel)
    - Replace list buffers with pre-allocated numpy arrays in CommandInterceptor
    - Eliminate np.concatenate() for audio output (single slice copy)
    - Vectorize PSG waveform generation
    - Add FPS counter to status bar
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2025-12-24 Add fullscreen CLI option and fix audio clipping
    - Add --fullscreen/-f flag to start in fullscreen mode
    - Use borderless windowed fullscreen for OBS capture compatibility
    - Fix audio clipping by scaling FM output (0.45) and PSG (0.15)
    [stream_vgm_visual.py]
2025-12-24 Add offline video recording with --record and --portrait options
    - Add --record <file.mp4> flag for built-in video capture
    - Add --portrait flag for 1080x1350 (4:5) Instagram-optimal aspect ratio
    - Implement offline rendering mode for perfect audio/video sync at 60fps
    - Use ffmpeg for H.264 encoding with AAC audio muxing
    - Support Ctrl+C for early exit with valid partial video output
    - Fix framebuffer rendering to avoid read/write same texture issue
    [stream_vgm_visual.py]
2025-12-24 Improve portrait mode layout and fix channel box alignment
    - Reduce waveform sample count in portrait mode (128 vs 256) for less condensed display
    - Increase status bar height in portrait mode (80px vs 60px)
    - Hide status/FPS text in portrait mode to reduce clutter
    - Use larger font for metadata in portrait mode
    - Fix channel box right edge alignment to match status bar width
    [stream_vgm_visual.py]
2025-12-24 Rebrand to SiliconMelody and clean up startup output
    - Replace FM-90s branding with SiliconMelody
    - Suppress pygame welcome message and deprecation warnings
    - Remove debug prints for font loading and shader compilation
    - Use larger SiliconMelody text when recording (no status bar)
    [stream_vgm_visual.py]
